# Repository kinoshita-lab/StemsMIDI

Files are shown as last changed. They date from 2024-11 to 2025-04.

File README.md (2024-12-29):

# STEMS MIDI: MIDI Controller for Traktor Stems (Dev board)

[日本語はこちら(Document in Japanese)](./README.ja.md)

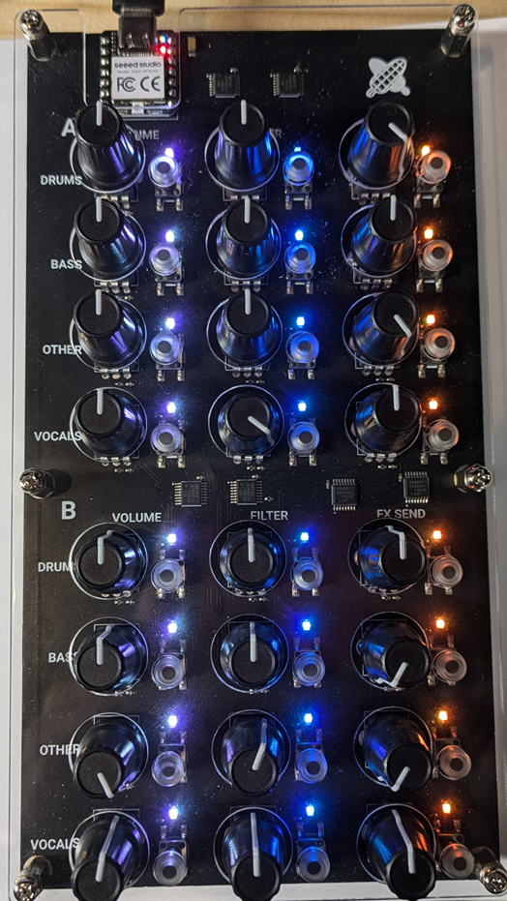
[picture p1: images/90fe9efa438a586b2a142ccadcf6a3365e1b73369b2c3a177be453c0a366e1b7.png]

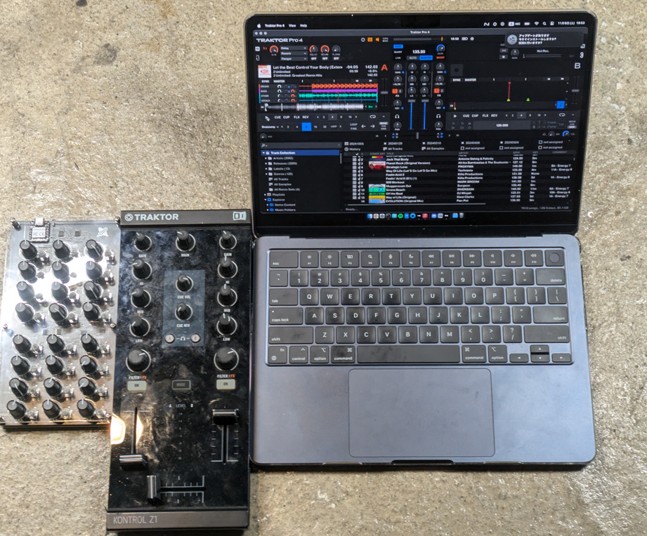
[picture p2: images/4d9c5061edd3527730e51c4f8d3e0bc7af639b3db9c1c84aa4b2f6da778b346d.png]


## ChangeLog
### Software
releases (https://github.com/kinoshita-lab/StemsMIDI/releases)

### Hardware Rev. 1.1
- [Hardware] Remove center-click feature for Vol and Effect knobs
- [Hardware] Add testing terminals on PCB

## Kit Contents

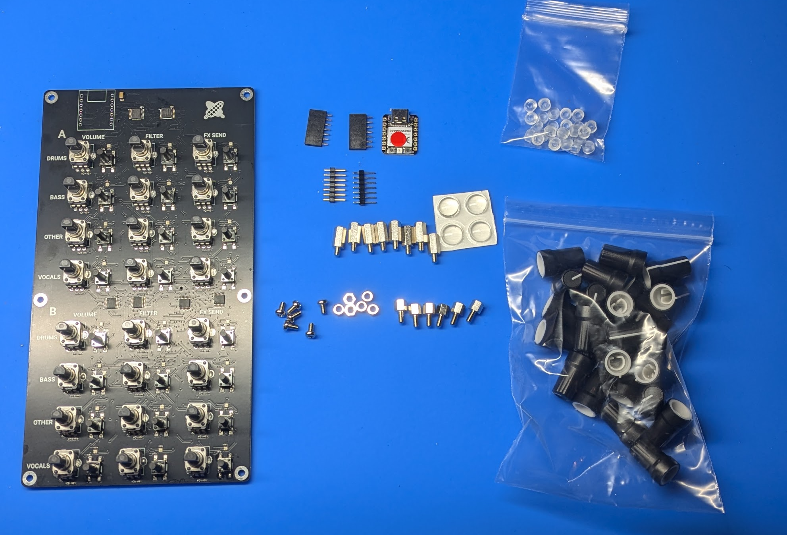
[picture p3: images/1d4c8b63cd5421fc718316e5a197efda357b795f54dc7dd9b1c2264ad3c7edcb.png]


- Pre-assembled PCB
- MCU Module Seeeduino XIAO RP2040(with flashed "sample" program)
- Pin Socket 1x7 (2 pcs.)
- Pin Header 1x7 (2 pcs.)
- Knob Caps (24 pcs.)
- Tactile switch Caps (24 pcs.)
- M3 Nuts (6 pcs.)
- M3 10mm Hex Spacers (6 pcs.)
- M3 7mm Hex Spacers (6 pcs.)
- M3 Screws (6 pcs.)
- Rubber feet pads(4 pcs.)
- Bottom Acrylic Panel (1 pcs.)
- Top Acrylic Panel (1 pcs.)

## Requied Equipments

- Solder Iron, Solder
- No.2 + Driver
- Plier and/or Wrench (for tightening nuts)

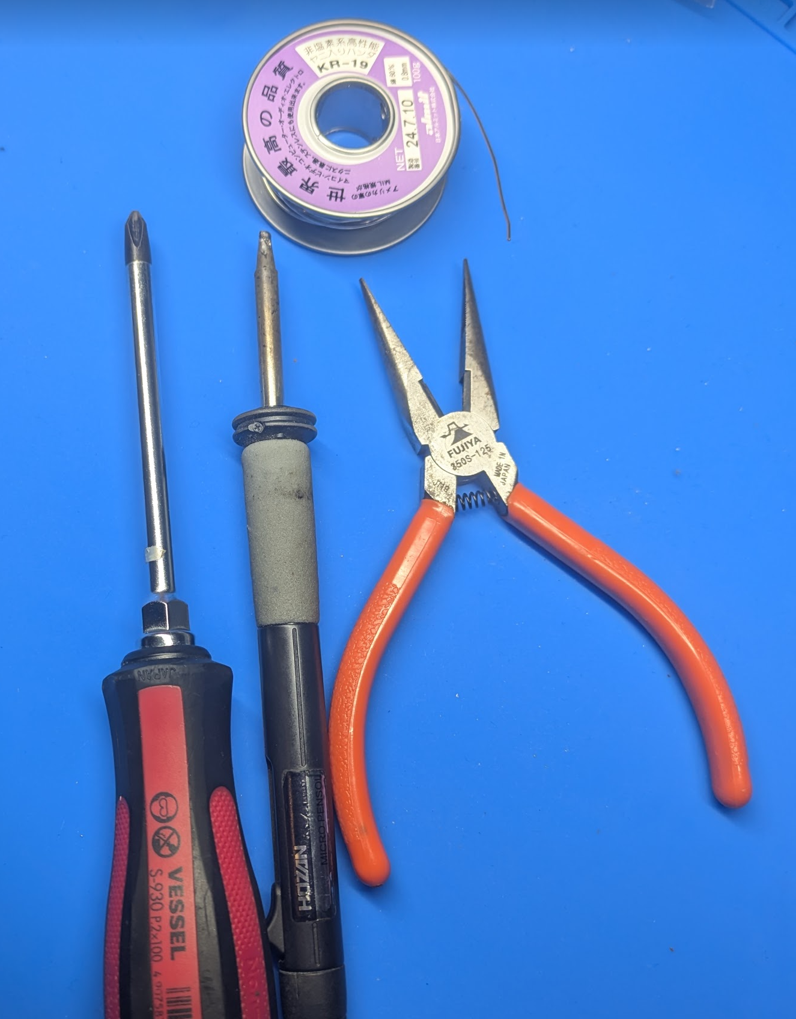
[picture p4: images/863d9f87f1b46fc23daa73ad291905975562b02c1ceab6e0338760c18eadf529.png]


## How to assemble

### Assemble the MCU Module

Recommend following procedure to align pins.
tips: You can solder MCU Module directly on the PCBA board.

Solder Pin Sockets, Pin Headers, and MCU. 1st, combine Pin Sockets and Headers as show below:

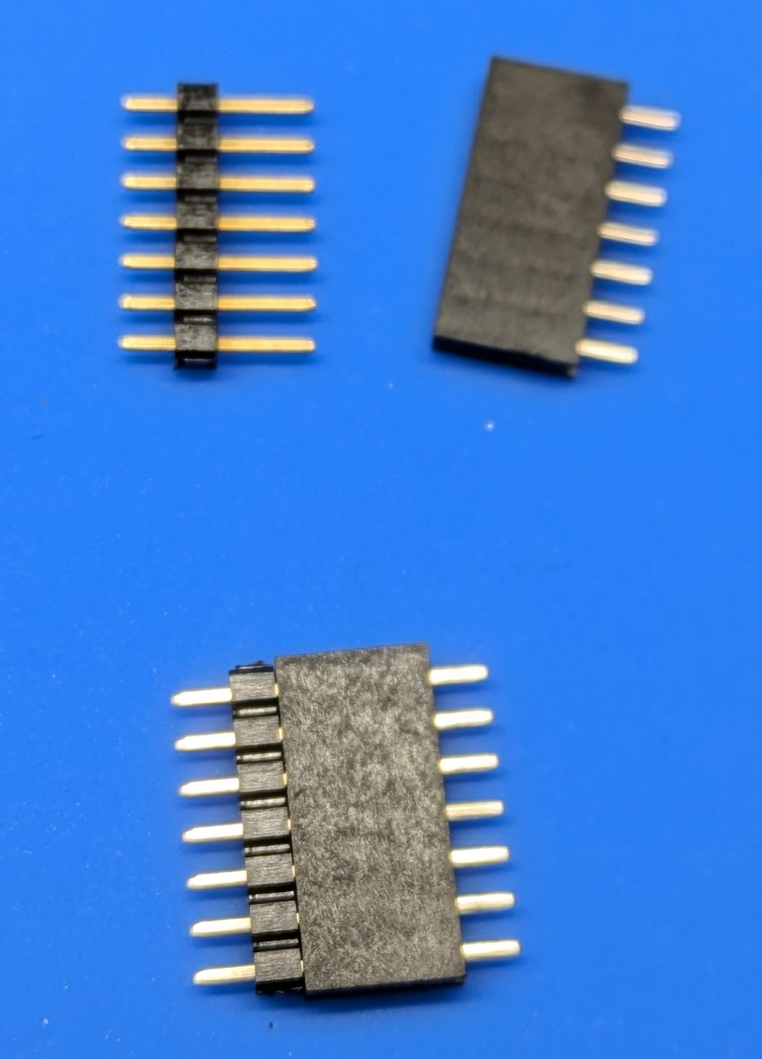
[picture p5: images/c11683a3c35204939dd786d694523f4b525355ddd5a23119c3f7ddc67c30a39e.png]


Put above result into MCU's both side holes as shown below:

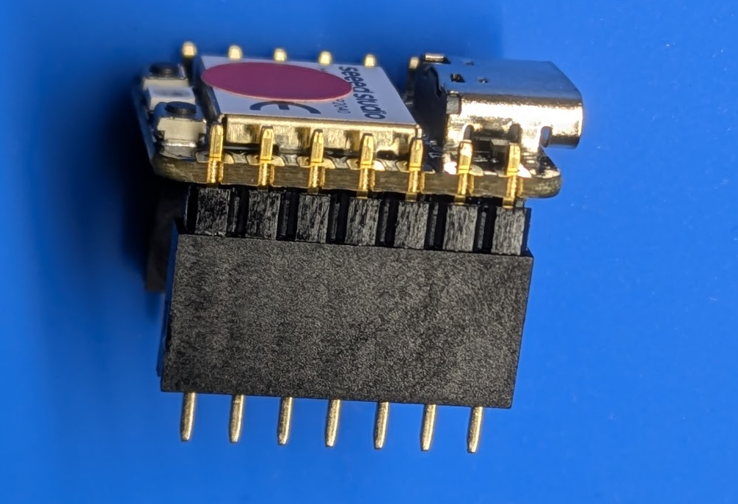
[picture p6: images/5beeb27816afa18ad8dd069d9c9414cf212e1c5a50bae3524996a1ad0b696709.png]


Put them on the holes of PCBA below:

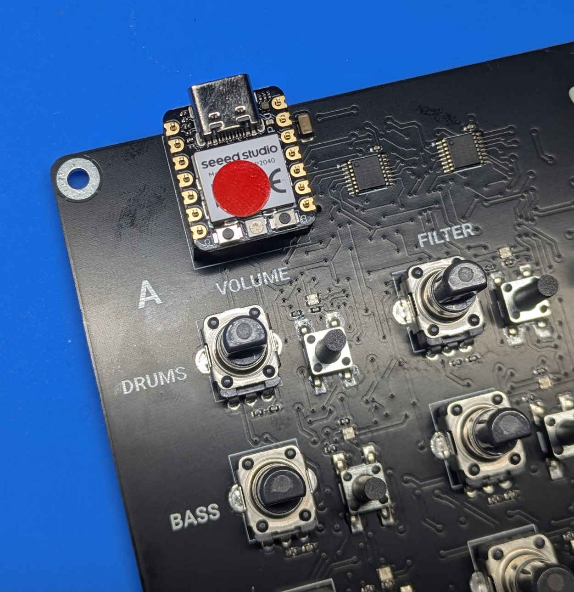
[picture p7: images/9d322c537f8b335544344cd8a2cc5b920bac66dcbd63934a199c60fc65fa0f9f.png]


Solder the Pin Header's MCU side:

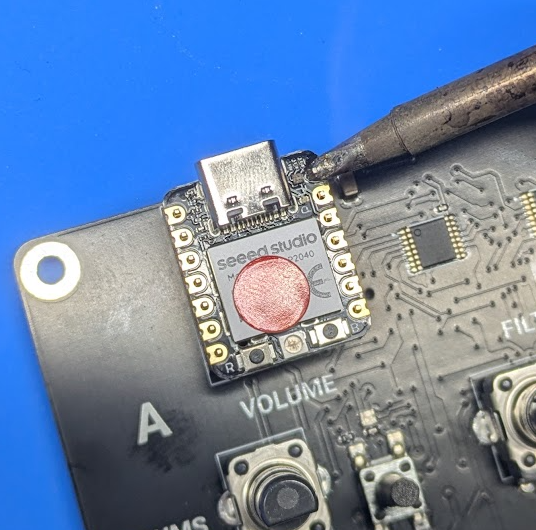
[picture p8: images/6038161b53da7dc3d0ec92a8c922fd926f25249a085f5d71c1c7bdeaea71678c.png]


Looks like below:

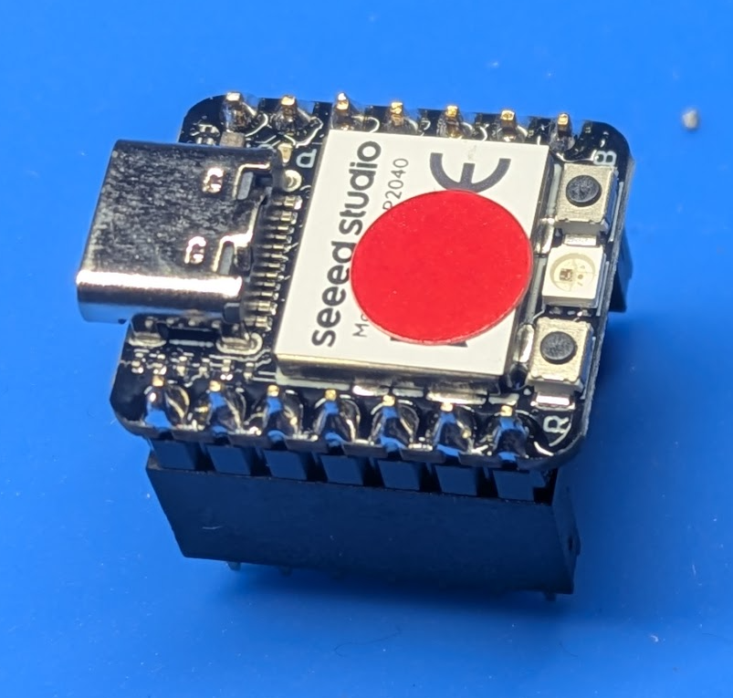
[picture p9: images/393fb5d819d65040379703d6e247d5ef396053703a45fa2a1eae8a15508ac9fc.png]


Put it again on the PCBA's holes:



Flip the PCBA board while holding the MCU module, with placing knob cap between MCU and the desk so that it can be held in place by its own weight.

Looks like below:

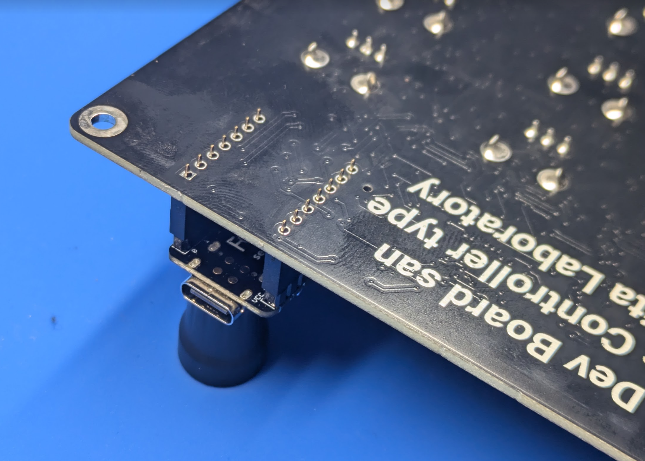
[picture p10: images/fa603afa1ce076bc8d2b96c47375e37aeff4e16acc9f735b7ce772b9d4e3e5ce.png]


Solder all the Pin socket's pin:

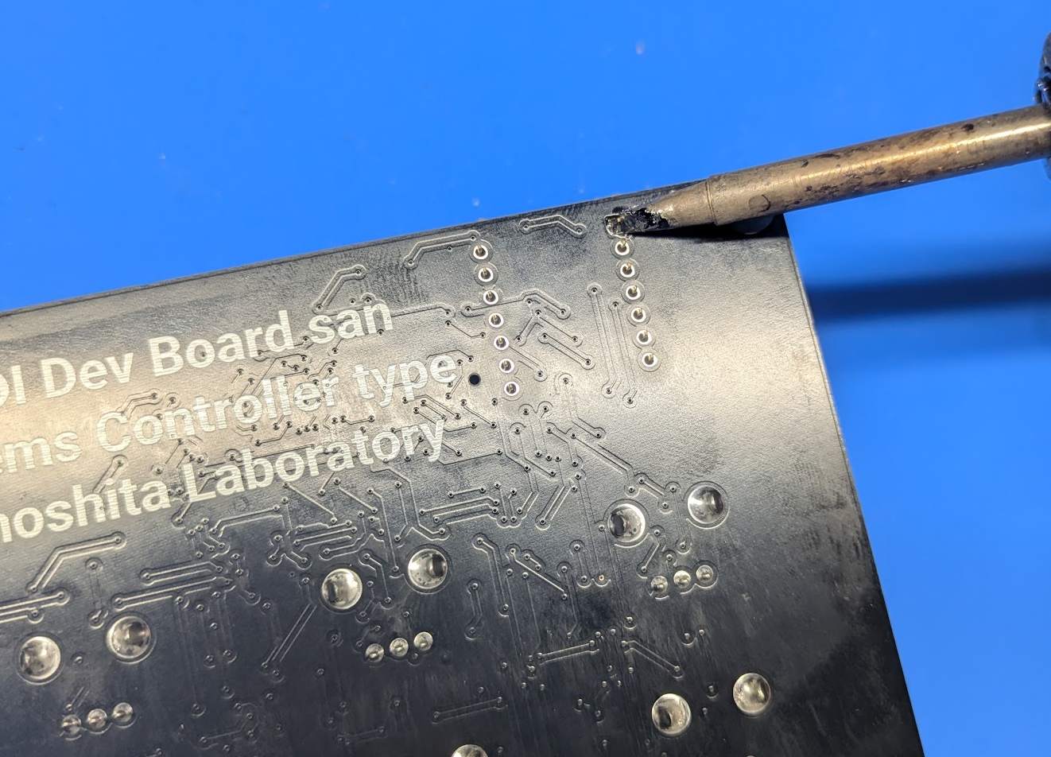
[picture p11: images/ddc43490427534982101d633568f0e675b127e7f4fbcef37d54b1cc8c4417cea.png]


### Assembling case

Peel off the protective sheet from the bottom acrylic panel, and attach nuts, M3  7mm Hex spacers hex screws (the shorter ones) at six locations.
(There are no two sides to the acrylic.):

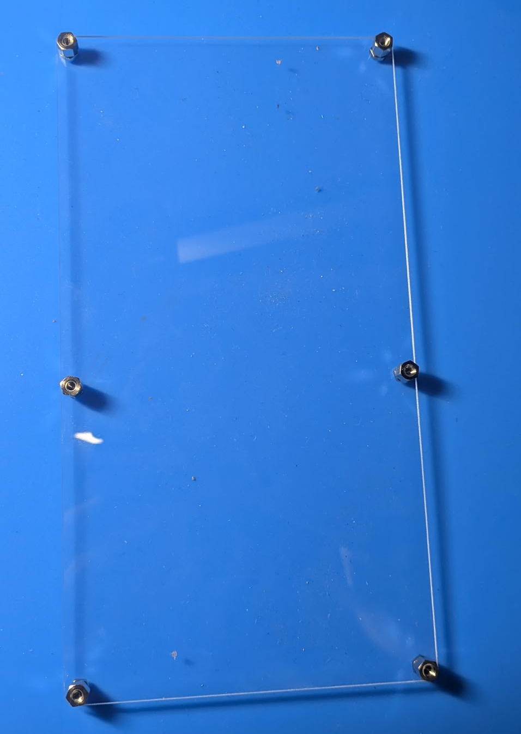
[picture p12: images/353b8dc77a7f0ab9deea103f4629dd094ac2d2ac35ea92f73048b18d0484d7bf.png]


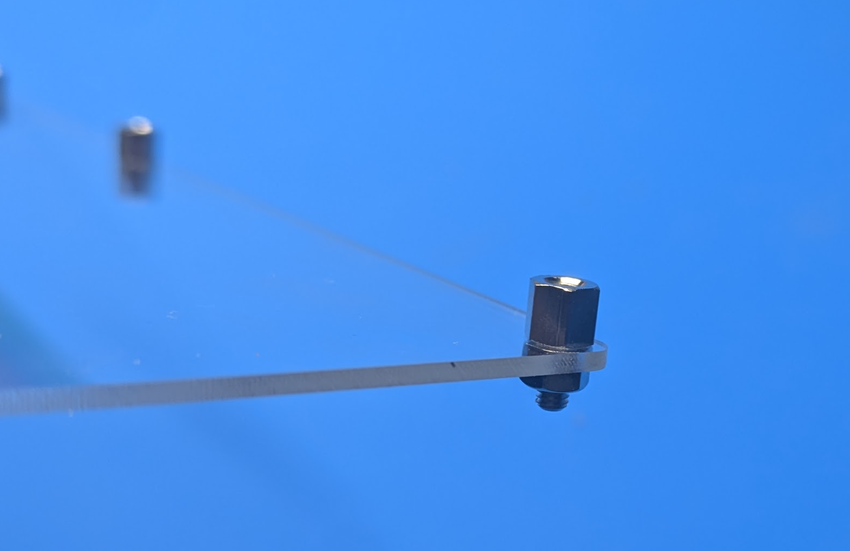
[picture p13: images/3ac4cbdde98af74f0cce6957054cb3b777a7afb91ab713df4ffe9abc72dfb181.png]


Put PCBA bord on it, tighten with the M3 10mm hex screws (the longer ones).
Tighten each screw little by little at to align the overall position:

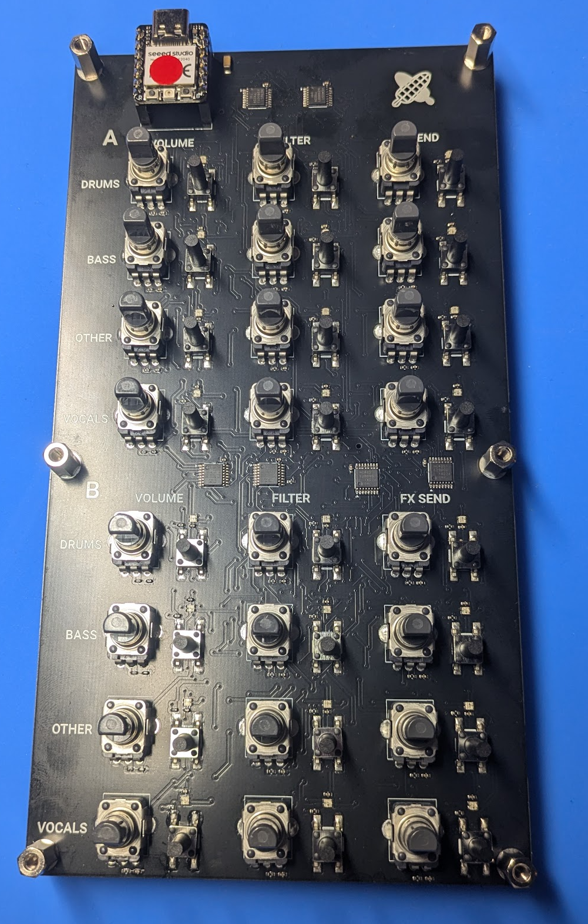
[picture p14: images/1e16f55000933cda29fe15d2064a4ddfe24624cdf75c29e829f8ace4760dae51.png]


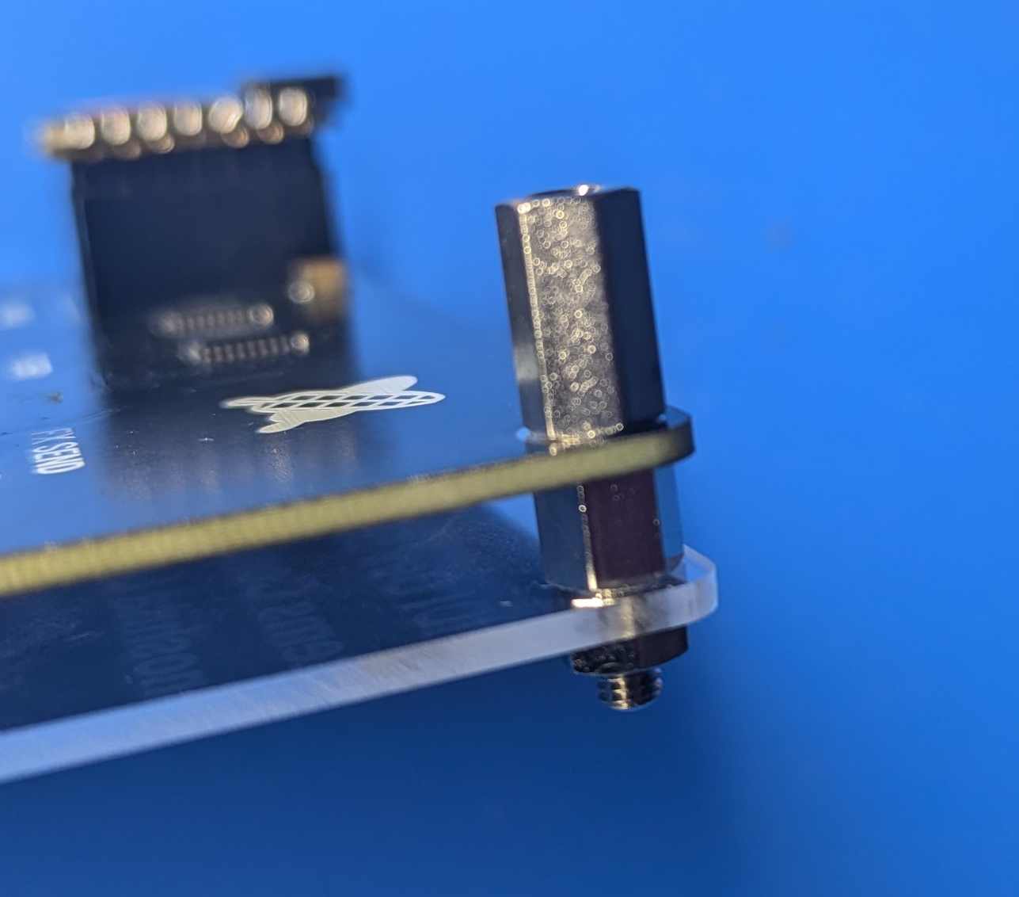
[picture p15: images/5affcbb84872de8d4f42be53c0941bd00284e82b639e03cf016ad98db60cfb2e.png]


Peel of the protective sheet from top acrylic panel and put it on the PCBA.
Tighten them with M3 screws.
Again, tighten each screw little by little at to align the overall position:

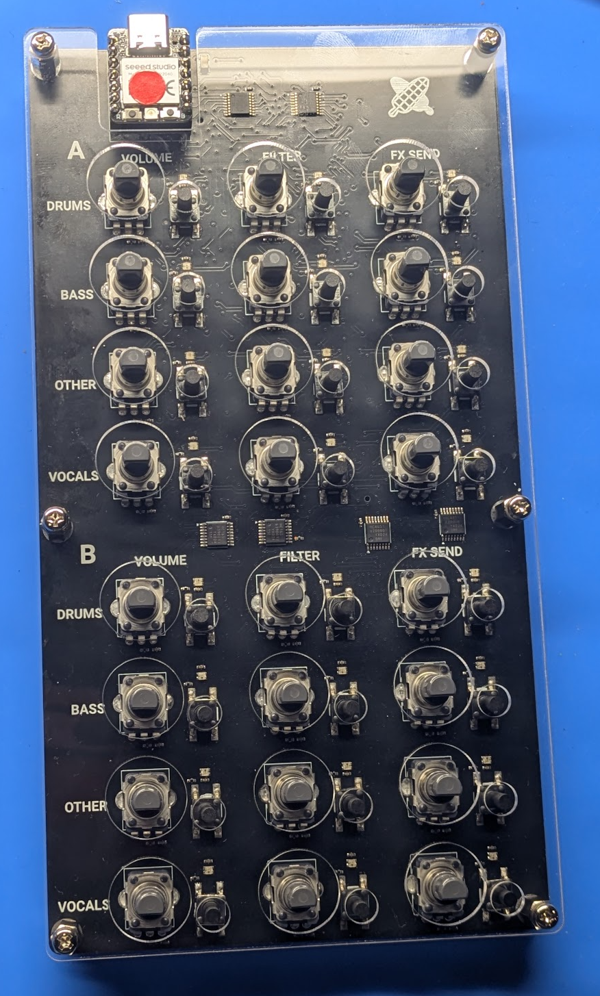
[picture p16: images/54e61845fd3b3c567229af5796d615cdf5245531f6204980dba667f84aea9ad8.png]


Put rubber feets on the bottom:

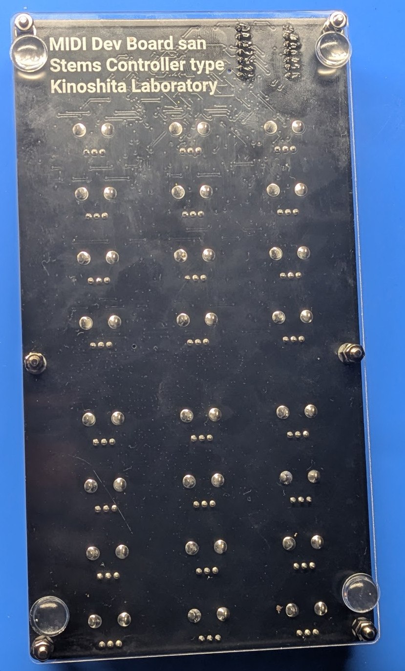
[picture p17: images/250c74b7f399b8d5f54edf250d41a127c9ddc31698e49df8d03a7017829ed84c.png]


Place knob caps:

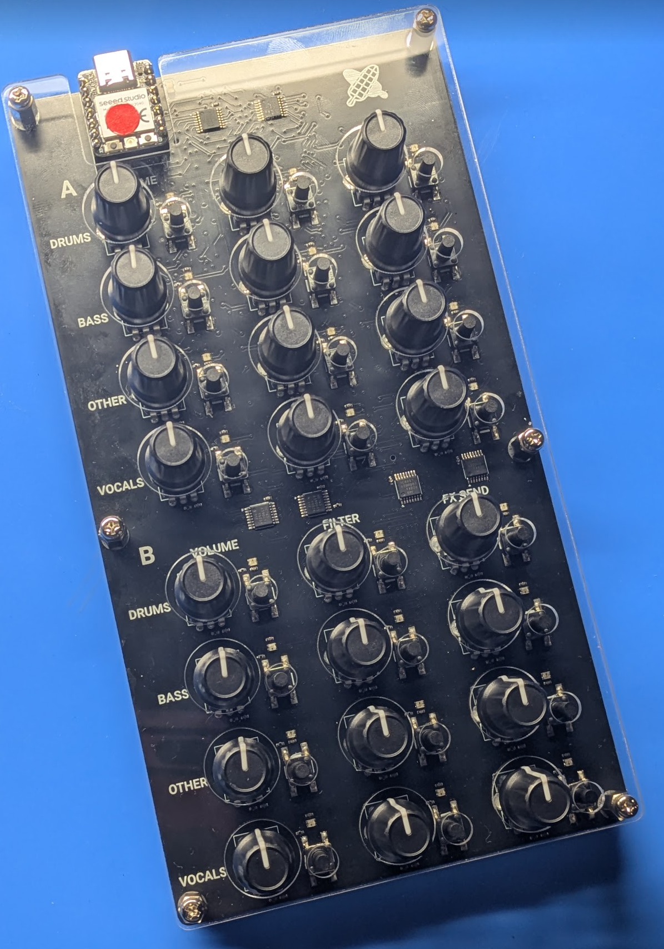
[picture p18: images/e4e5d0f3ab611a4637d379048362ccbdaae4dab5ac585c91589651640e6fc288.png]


Place tactile switch caps:

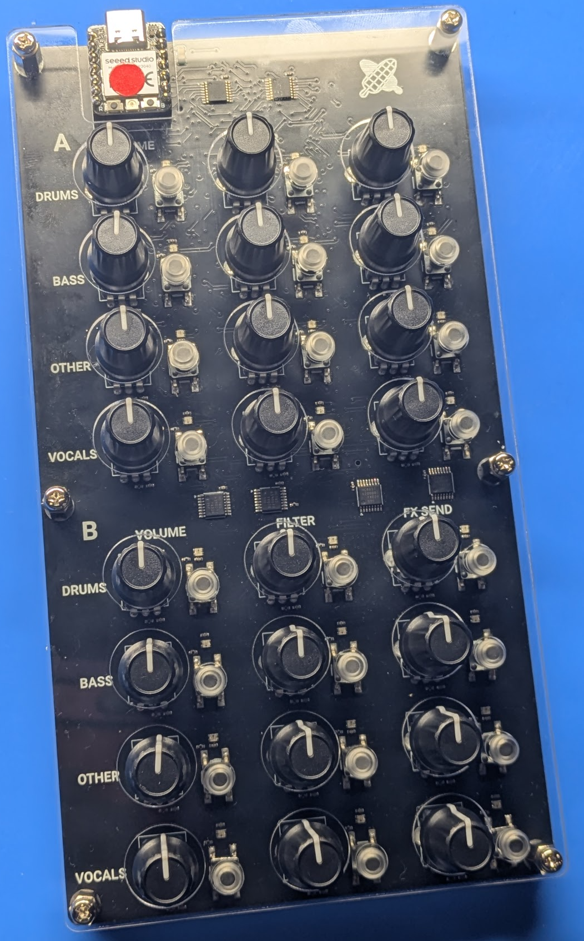
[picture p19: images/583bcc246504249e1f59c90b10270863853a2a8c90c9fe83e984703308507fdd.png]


## Usage

- Connect the product to PC/MAC.
- Import .tsi file below on Traktor.

<https://github.com/kinoshita-lab/StemsMIDI/tree/main/Traktor%20Setting>

## How to update Software

What you will need:

- Latest software to be flashed to the MCU(firmware.uf2) download from <https://github.com/kinoshita-lab/StemsMIDI/releases>
- PC or mac

Connect the USB cable with pressing the **B** button on the right bottom of the MCU.
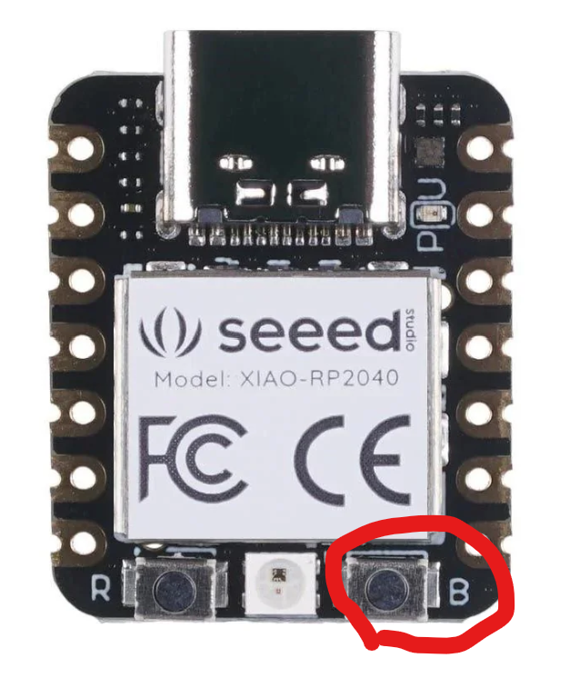
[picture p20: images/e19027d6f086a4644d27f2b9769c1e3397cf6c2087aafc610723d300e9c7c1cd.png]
  

After releasing the button, disk drive will appear on you PC/mac. The drive name is `RP-RP2`.

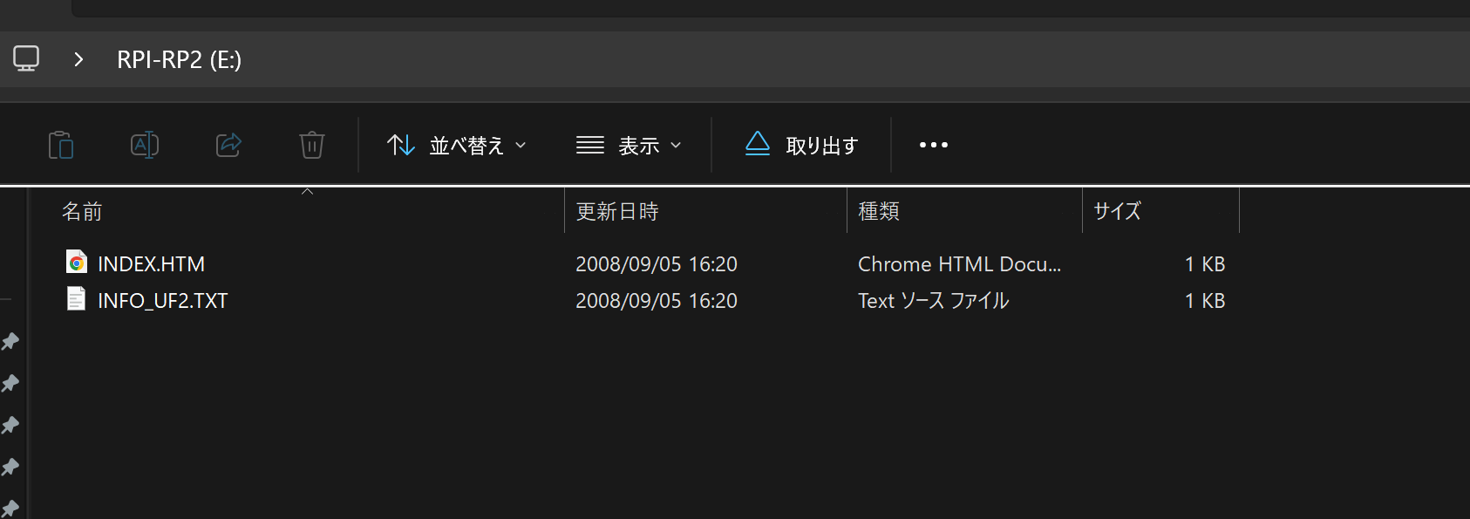
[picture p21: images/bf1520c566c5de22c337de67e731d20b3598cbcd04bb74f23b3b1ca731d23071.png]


Copy the firmware.uf2 file to the drive.
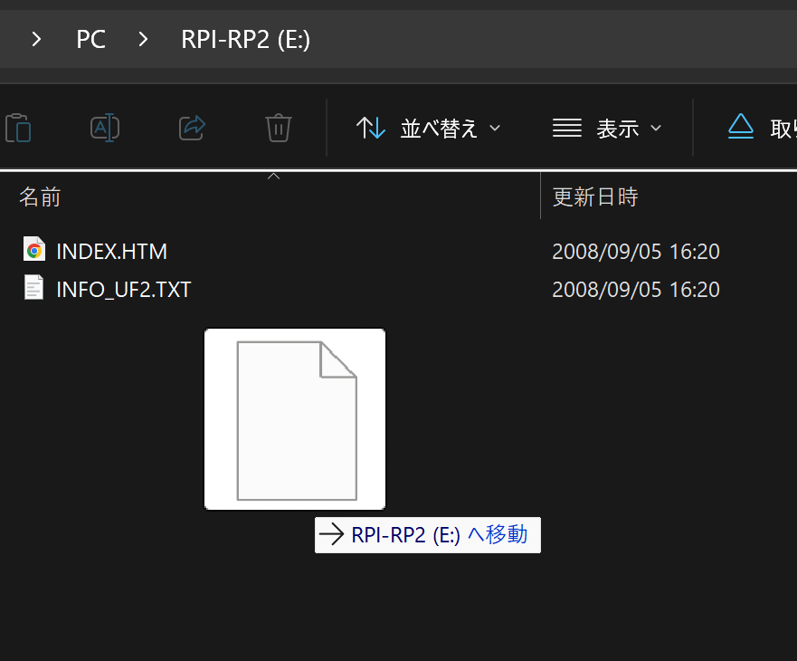
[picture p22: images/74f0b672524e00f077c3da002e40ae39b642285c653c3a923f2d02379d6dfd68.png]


Done updating, drive will automatically closed.

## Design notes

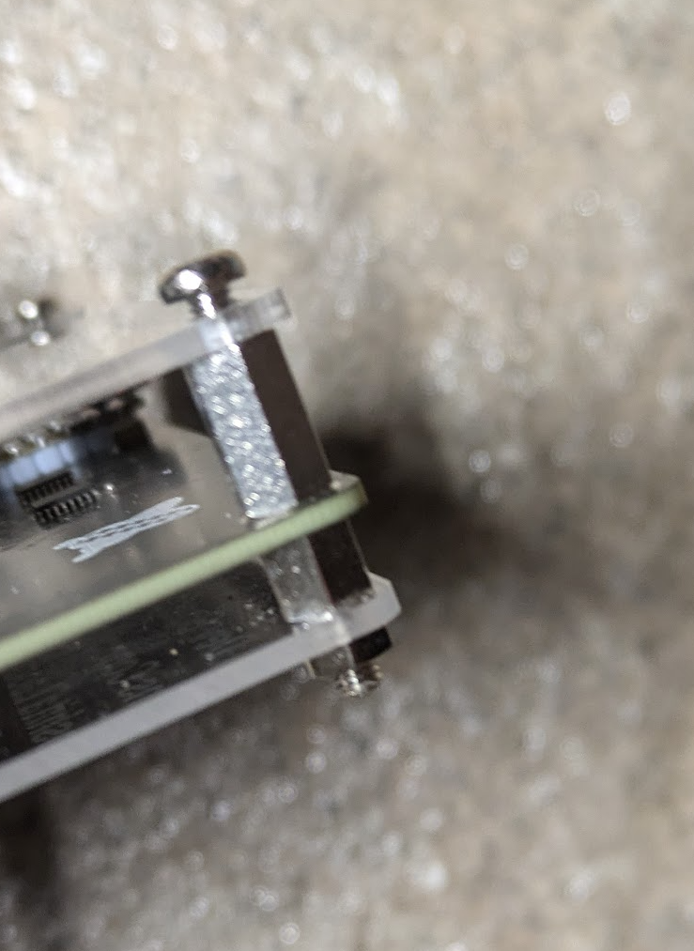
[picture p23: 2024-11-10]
images/7f1cb6cd50c7bb32835a7ec60418512192629a608fd293ecf4b8e06034ae1c80.png

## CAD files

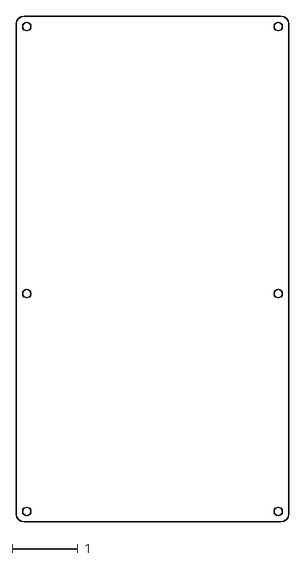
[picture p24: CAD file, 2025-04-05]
hard/Case/StemsMIDI_Case_Bottom-Edge_Cuts.dxf
4.13 x 7.68

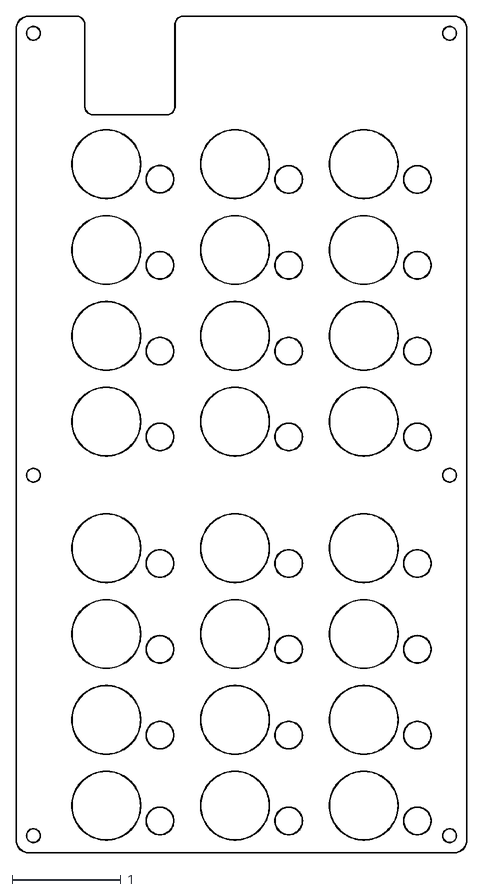
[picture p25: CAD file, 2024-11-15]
hard/Case/StemsMIDI_Case_Top_top-Edge_Cuts.dxf
4.14 x 7.68

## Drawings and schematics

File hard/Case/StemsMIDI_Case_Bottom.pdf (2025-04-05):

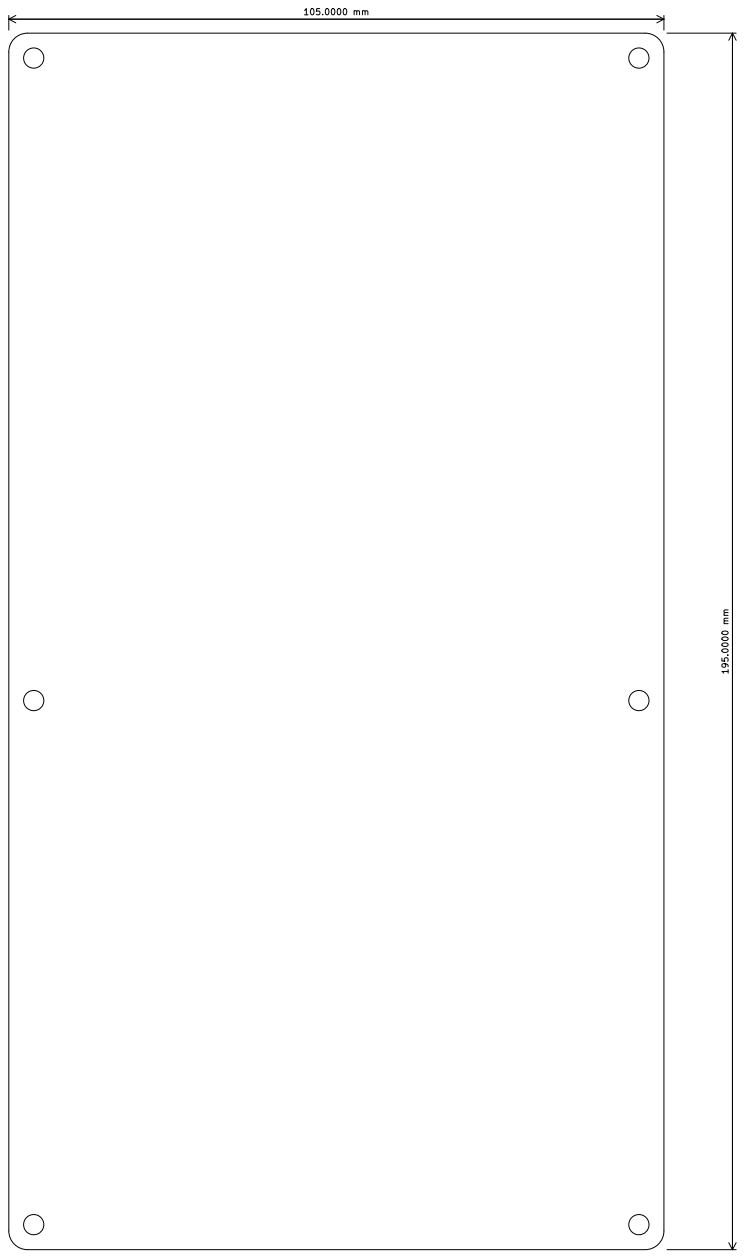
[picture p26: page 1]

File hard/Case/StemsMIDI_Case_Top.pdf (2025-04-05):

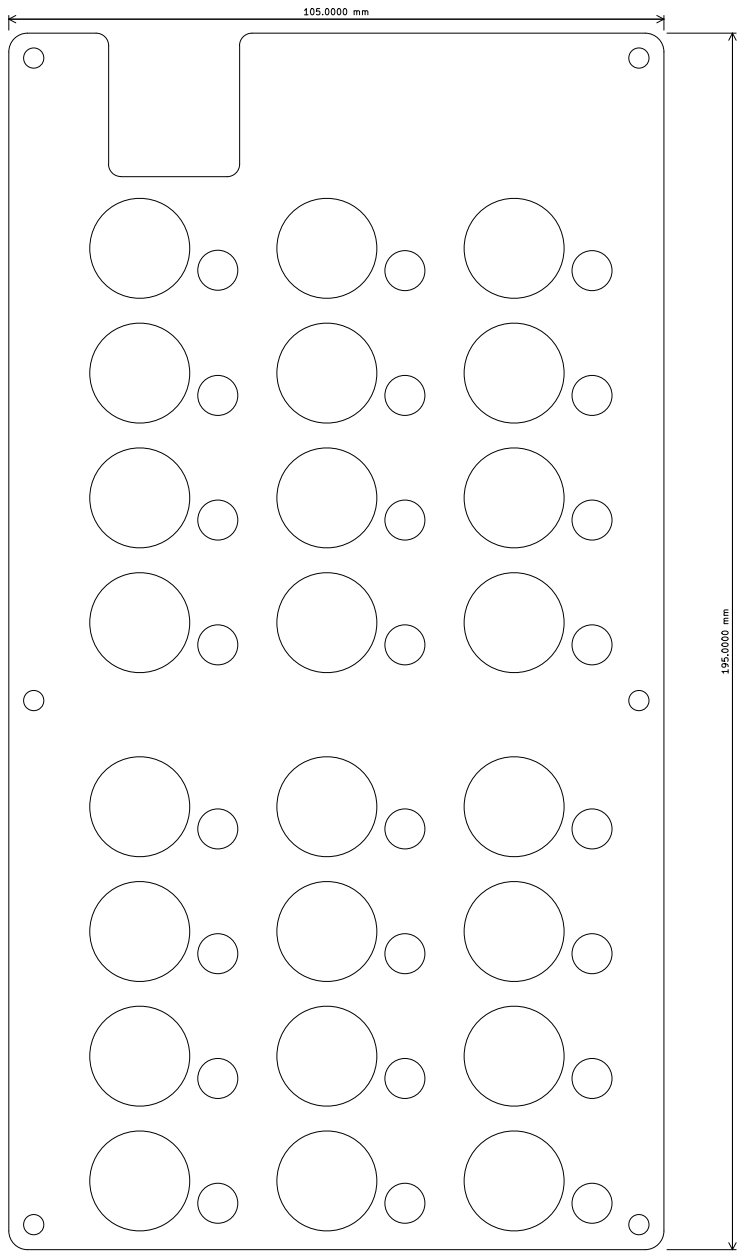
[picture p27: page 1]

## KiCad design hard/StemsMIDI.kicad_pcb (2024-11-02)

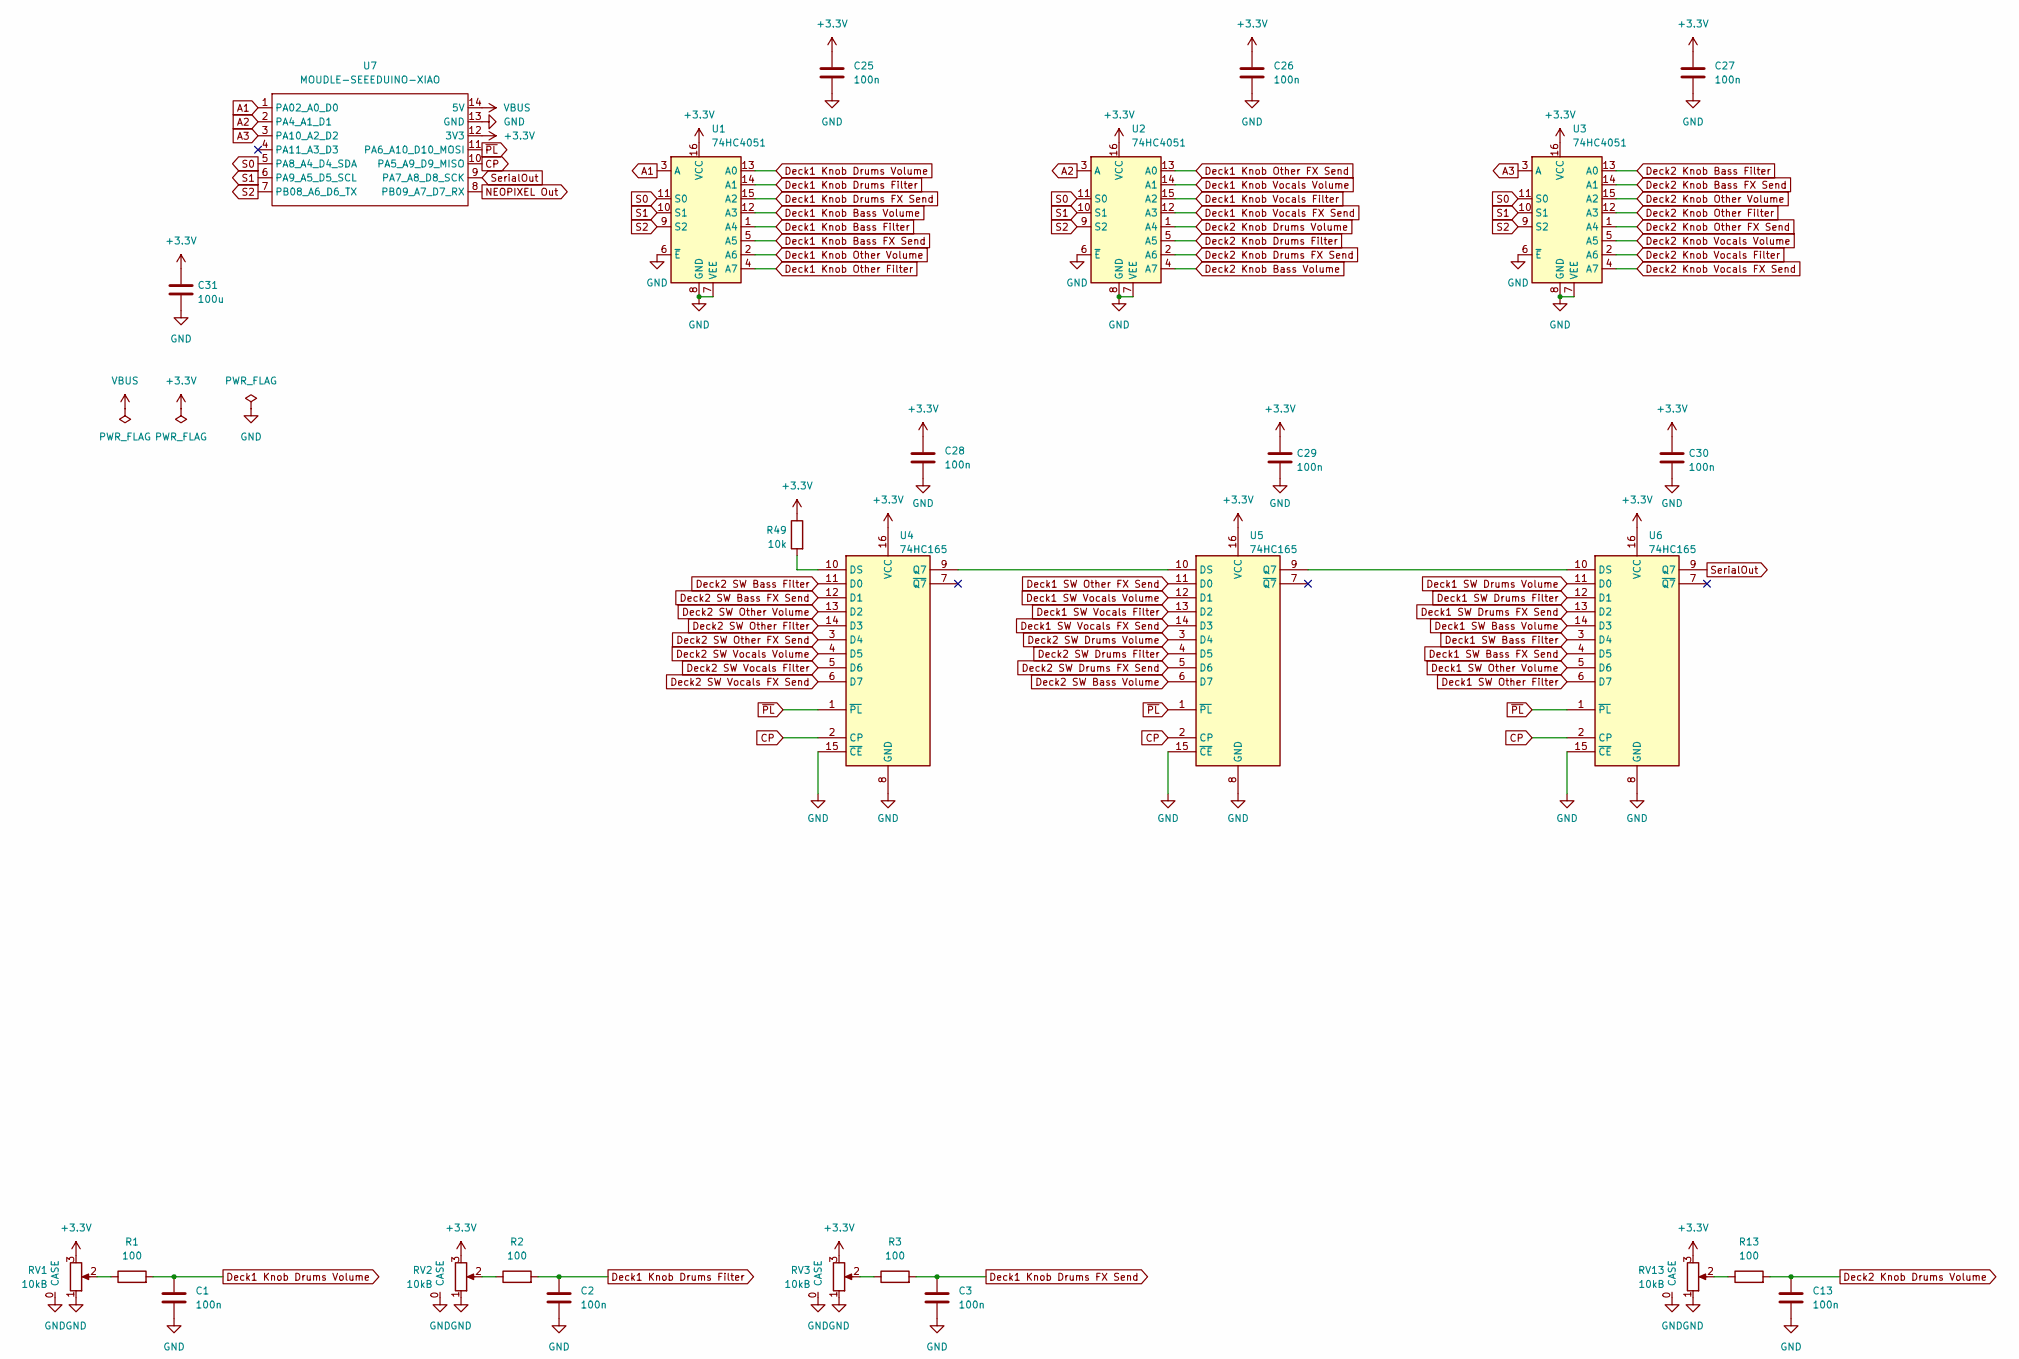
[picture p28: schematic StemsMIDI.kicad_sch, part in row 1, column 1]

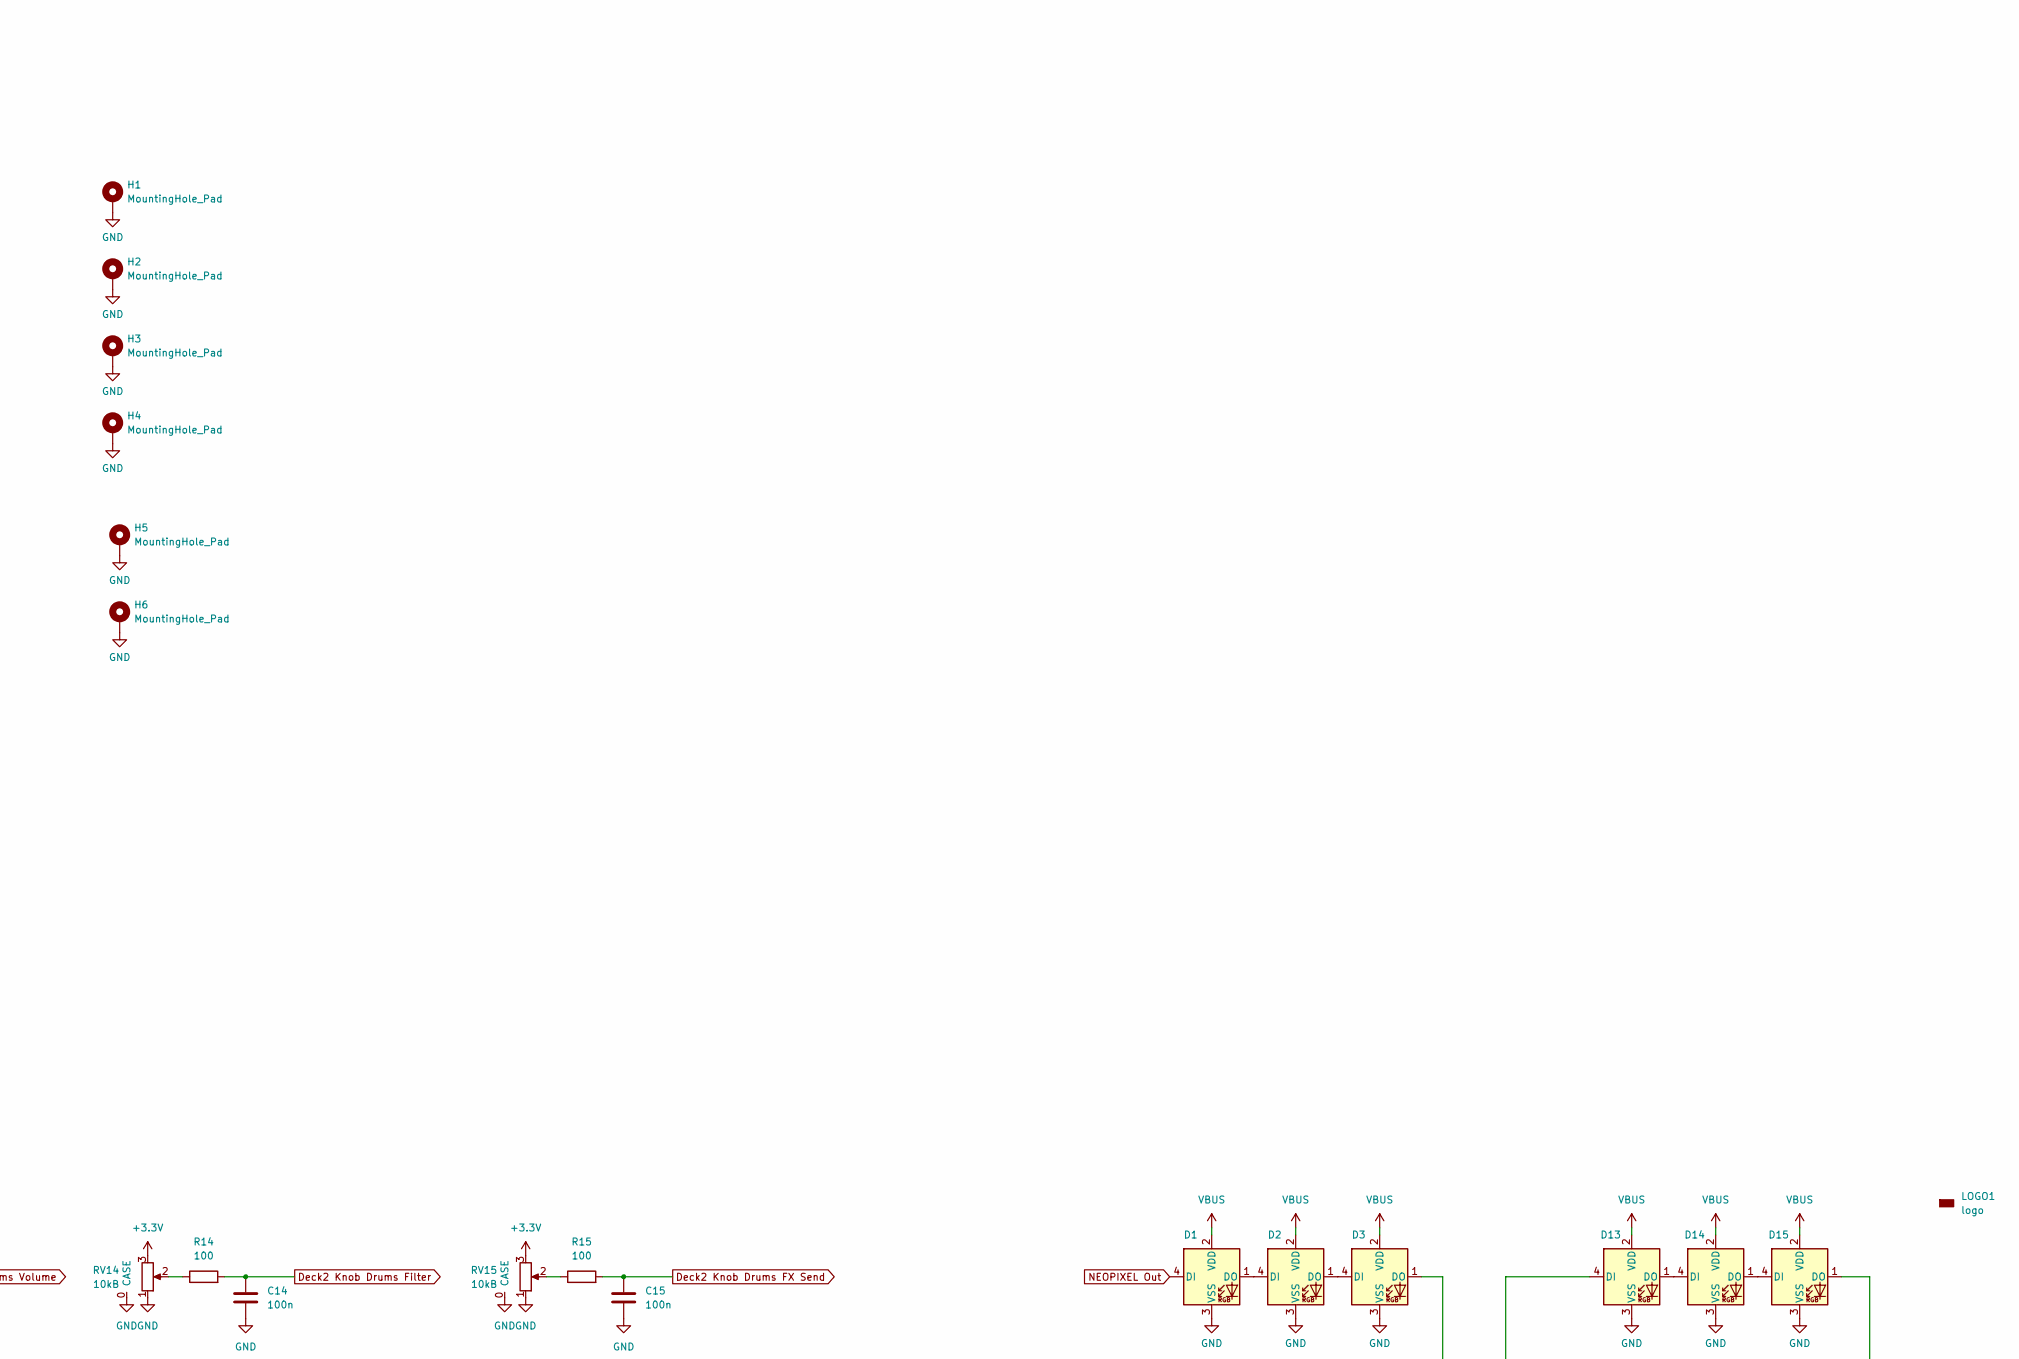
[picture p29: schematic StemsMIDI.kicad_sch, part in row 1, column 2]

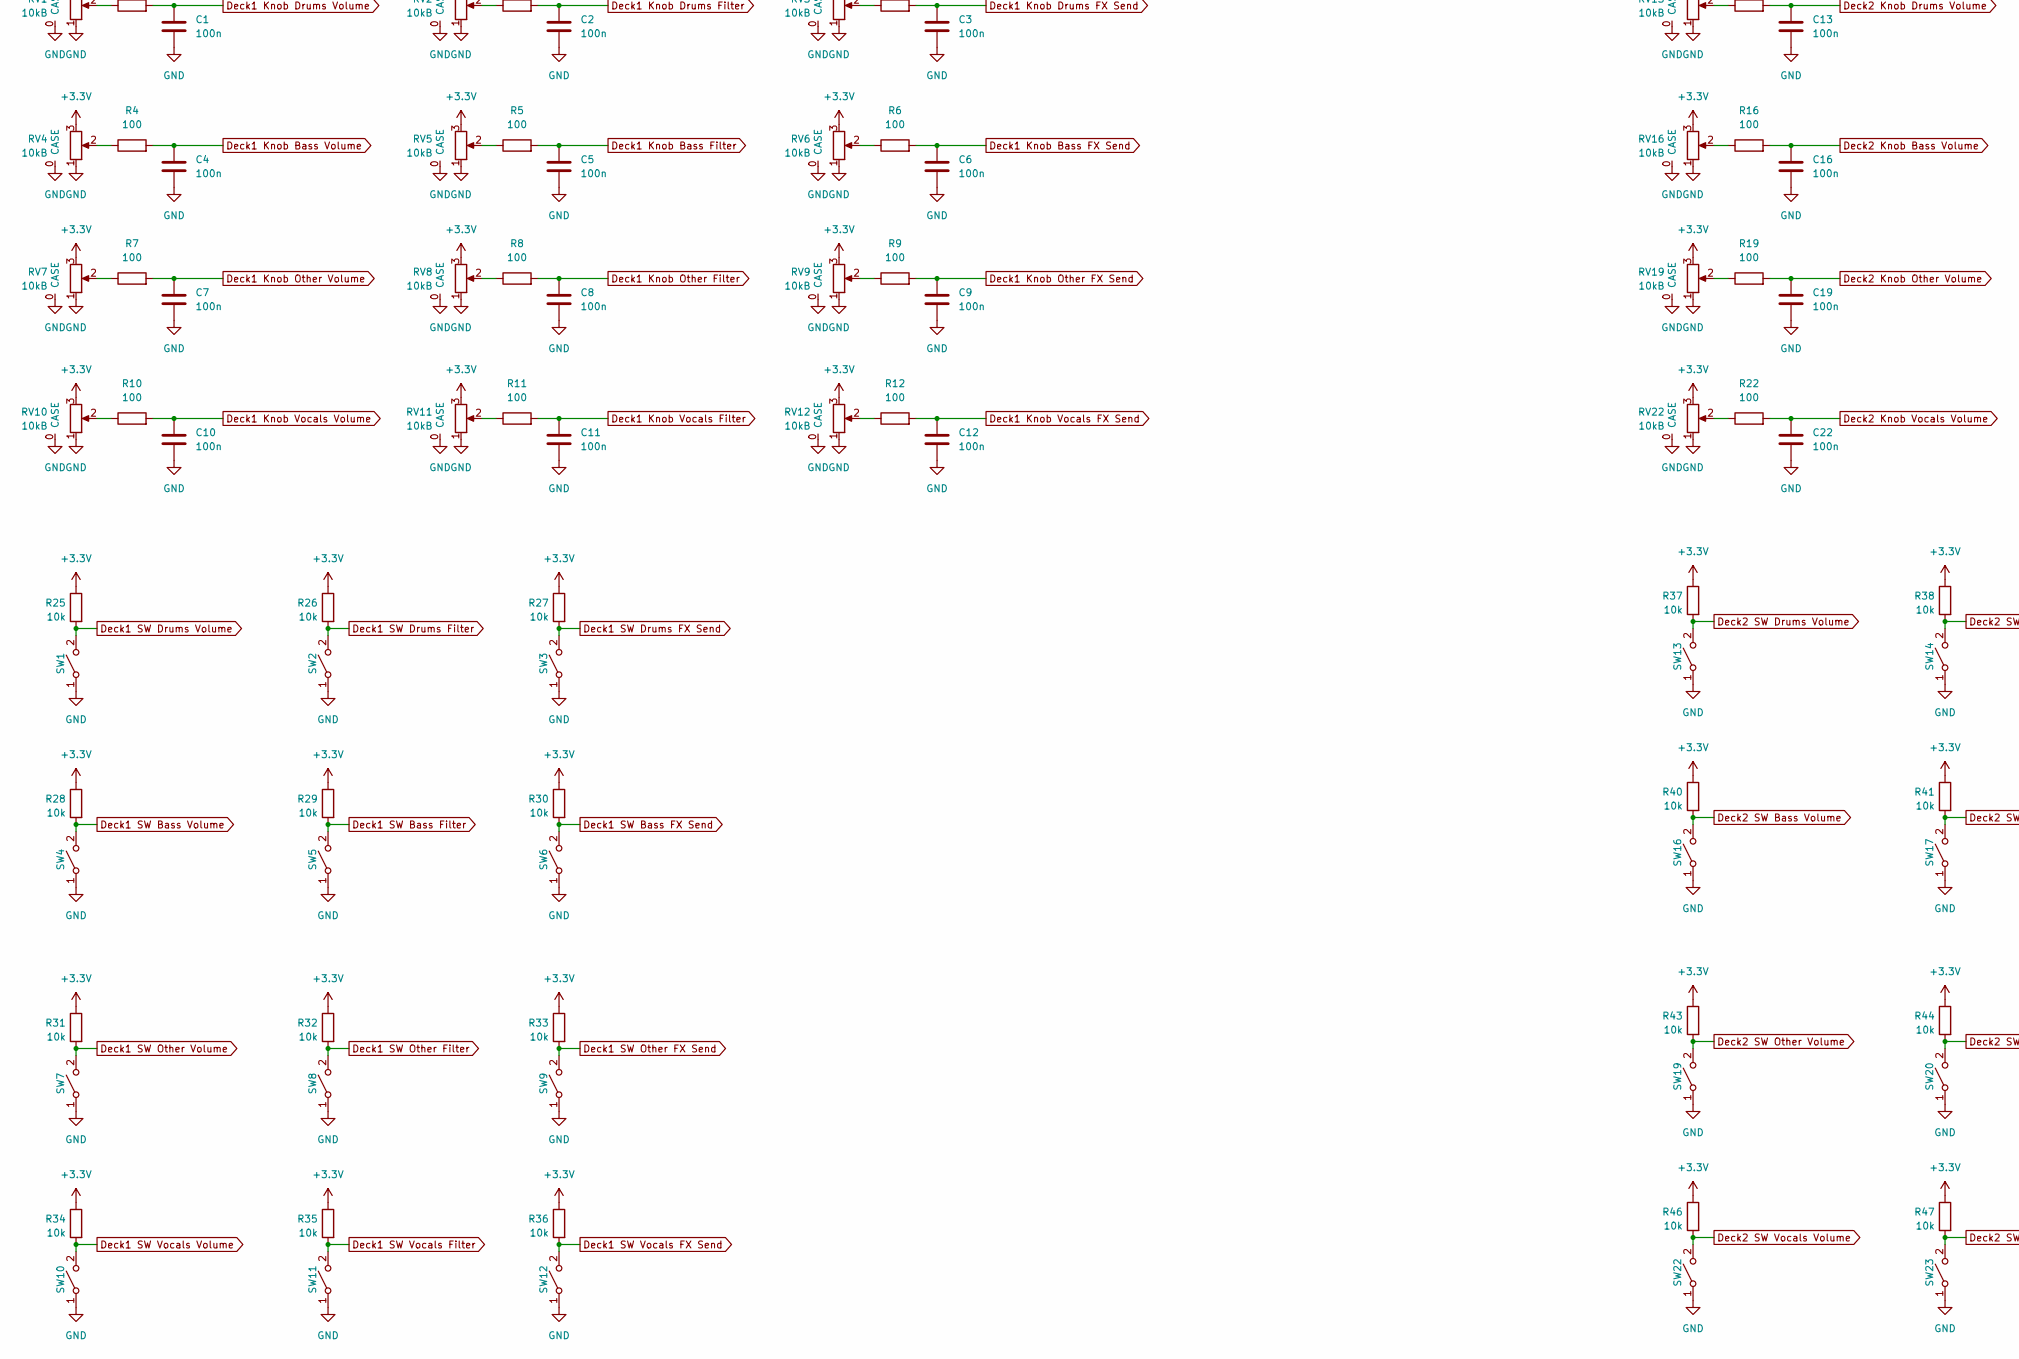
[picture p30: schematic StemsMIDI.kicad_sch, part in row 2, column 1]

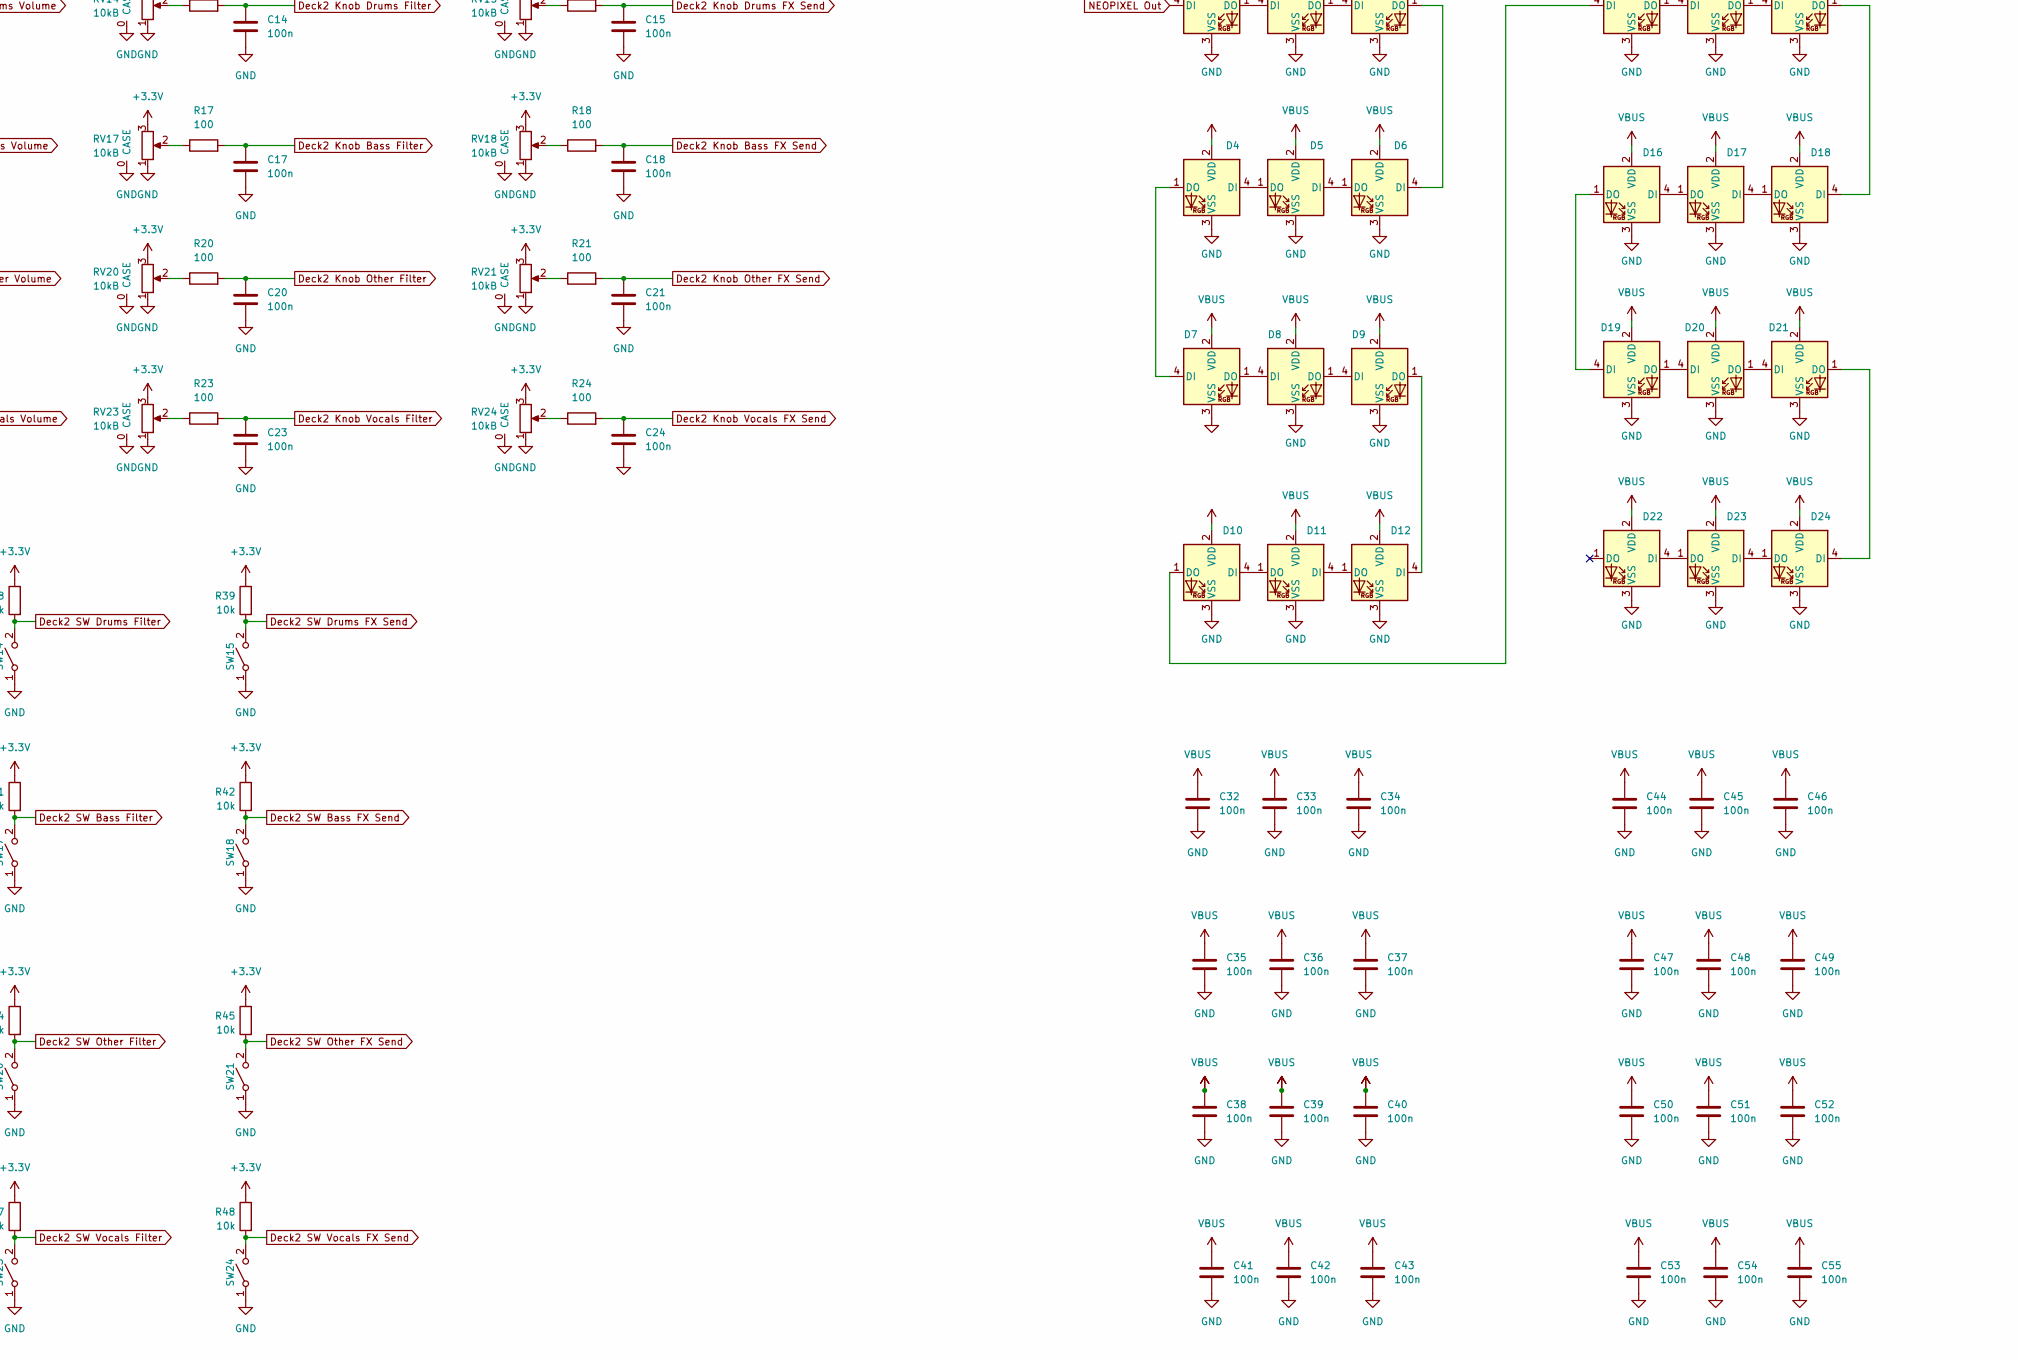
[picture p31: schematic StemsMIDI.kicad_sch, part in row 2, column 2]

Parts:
C1, C2, C3, C4, C5, C6, C7, C8, C9, C10, C11, C12, C13, C14, C15, C16, C17, C18, C19, C20, C21, C22, C23, C24, C25, C26, C27, C28, C29, C30, C32, C33, C34, C35, C36, C37, C38, C39, C40, C41, C42, C43, C44, C45, C46, C47, C48, C49, C50, C51, C52, C53, C54, C55: 100n; C_0402_1005Metric_Pad0.74x0.62mm_HandSolder; LCSC C1525
C31: 100u; C_1206_3216Metric_Pad1.33x1.80mm_HandSolder; LCSC C312983
D1, D2, D3, D4, D5, D6, D7, D8, D9, D10, D11, D12, D13, D14, D15, D16, D17, D18, D19, D20, D21, D22, D23, D24: LED_NeoPixel_XL-1615RGBC-WS2812B; LCSC C5349954
H1, H2, H3, H4, H5, H6: MountingHole_Pad; MountingHole_3.2mm_M3_Pad
LOGO1: logo; kinoshita-logo_simplified_300dpi
R1, R2, R3, R4, R5, R6, R7, R8, R9, R10, R11, R12, R13, R14, R15, R16, R17, R18, R19, R20, R21, R22, R23, R24: 100; R_0402_1005Metric_Pad0.72x0.64mm_HandSolder; LCSC C106232
R25, R26, R27, R28, R29, R30, R31, R32, R33, R34, R35, R36, R37, R38, R39, R40, R41, R42, R43, R44, R45, R46, R47, R48, R49: 10k; R_0402_1005Metric_Pad0.72x0.64mm_HandSolder; LCSC C25744
RV1, RV2, RV3, RV4, RV5, RV6, RV7, RV8, RV9, RV10, RV11, RV12, RV13, RV14, RV15, RV16, RV17, RV18, RV19, RV20, RV21, RV22, RV23, RV24: 10kB; Potentiometer_Alps_RK09K_Horizontal_CORRECTED; LCSC C470315
SW1, SW2, SW3, SW4, SW5, SW6, SW7, SW8, SW9, SW10, SW11, SW12, SW13, SW14, SW15, SW16, SW17, SW18, SW19, SW20, SW21, SW22, SW23, SW24: SW_SPST; SW_Tactile_6mm_x_6mm_Futsuuno_SMD; LCSC C2885193
U1, U2, U3: 74HC4051; TSSOP-16_4.4x5mm_P0.65mm; LCSC C5645
U4, U5, U6: 74HC165; TSSOP-16_4.4x5mm_P0.65mm; LCSC C80696
U7: MOUDLE-SEEEDUINO-XIAO; Seeduino_Xiao_RP2040_MOUDLE14P-2.54-21X17.8MM

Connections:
+3.3V: C25.1, C26.1, C27.1, C28.1, C29.1, C30.1, C31.1, R25.1, R26.1, R27.1, R28.1, R29.1, R30.1, R31.1, R32.1, R33.1, R34.1, R35.1, R36.1, R37.1, R38.1, R39.1, R40.1, R41.1, R42.1, R43.1, R44.1, R45.1, R46.1, R47.1, R48.1, R49.1, RV1.3, RV2.3, RV3.3, RV4.3, RV5.3, RV6.3, RV7.3, RV8.3, RV9.3, RV10.3, RV11.3, RV12.3, RV13.3, RV14.3, RV15.3, RV16.3, RV17.3, RV18.3, RV19.3, RV20.3, RV21.3, RV22.3, RV23.3, RV24.3, U1.16 (VCC), U2.16 (VCC), U3.16 (VCC), U4.16 (VCC), U5.16 (VCC), U6.16 (VCC), U7.12 (3V3)
A1: U1.3 (A), U7.1 (PA02_A0_D0)
A2: U2.3 (A), U7.2 (PA4_A1_D1)
A3: U3.3 (A), U7.3 (PA10_A2_D2)
CP: U4.2 (CP), U5.2 (CP), U6.2 (CP), U7.10 (PA5_A9_D9_MISO)
Deck1 Knob Bass FX Send: C6.1, R6.2, U1.5 (A5)
Deck1 Knob Bass Filter: C5.1, R5.2, U1.1 (A4)
Deck1 Knob Bass Volume: C4.1, R4.2, U1.12 (A3)
Deck1 Knob Drums FX Send: C3.1, R3.2, U1.15 (A2)
Deck1 Knob Drums Filter: C2.1, R2.2, U1.14 (A1)
Deck1 Knob Drums Volume: C1.1, R1.2, U1.13 (A0)
Deck1 Knob Other FX Send: C9.1, R9.2, U2.13 (A0)
Deck1 Knob Other Filter: C8.1, R8.2, U1.4 (A7)
Deck1 Knob Other Volume: C7.1, R7.2, U1.2 (A6)
Deck1 Knob Vocals FX Send: C12.1, R12.2, U2.12 (A3)
Deck1 Knob Vocals Filter: C11.1, R11.2, U2.15 (A2)
Deck1 Knob Vocals Volume: C10.1, R10.2, U2.14 (A1)
Deck1 SW Bass FX Send: R30.2, SW6.2 (B), U6.4 (D5)
Deck1 SW Bass Filter: R29.2, SW5.2 (B), U6.3 (D4)
Deck1 SW Bass Volume: R28.2, SW4.2 (B), U6.14 (D3)
Deck1 SW Drums FX Send: R27.2, SW3.2 (B), U6.13 (D2)
Deck1 SW Drums Filter: R26.2, SW2.2 (B), U6.12 (D1)
Deck1 SW Drums Volume: R25.2, SW1.2 (B), U6.11 (D0)
Deck1 SW Other FX Send: R33.2, SW9.2 (B), U5.11 (D0)
Deck1 SW Other Filter: R32.2, SW8.2 (B), U6.6 (D7)
Deck1 SW Other Volume: R31.2, SW7.2 (B), U6.5 (D6)
Deck1 SW Vocals FX Send: R36.2, SW12.2 (B), U5.14 (D3)
Deck1 SW Vocals Filter: R35.2, SW11.2 (B), U5.13 (D2)
Deck1 SW Vocals Volume: R34.2, SW10.2 (B), U5.12 (D1)
Deck2 Knob Bass FX Send: C18.1, R18.2, U3.14 (A1)
Deck2 Knob Bass Filter: C17.1, R17.2, U3.13 (A0)
Deck2 Knob Bass Volume: C16.1, R16.2, U2.4 (A7)
Deck2 Knob Drums FX Send: C15.1, R15.2, U2.2 (A6)
Deck2 Knob Drums Filter: C14.1, R14.2, U2.5 (A5)
Deck2 Knob Drums Volume: C13.1, R13.2, U2.1 (A4)
Deck2 Knob Other FX Send: C21.1, R21.2, U3.1 (A4)
Deck2 Knob Other Filter: C20.1, R20.2, U3.12 (A3)
Deck2 Knob Other Volume: C19.1, R19.2, U3.15 (A2)
Deck2 Knob Vocals FX Send: C24.1, R24.2, U3.4 (A7)
Deck2 Knob Vocals Filter: C23.1, R23.2, U3.2 (A6)
Deck2 Knob Vocals Volume: C22.1, R22.2, U3.5 (A5)
Deck2 SW Bass FX Send: R42.2, SW18.2 (B), U4.12 (D1)
Deck2 SW Bass Filter: R41.2, SW17.2 (B), U4.11 (D0)
Deck2 SW Bass Volume: R40.2, SW16.2 (B), U5.6 (D7)
Deck2 SW Drums FX Send: R39.2, SW15.2 (B), U5.5 (D6)
Deck2 SW Drums Filter: R38.2, SW14.2 (B), U5.4 (D5)
Deck2 SW Drums Volume: R37.2, SW13.2 (B), U5.3 (D4)
Deck2 SW Other FX Send: R45.2, SW21.2 (B), U4.3 (D4)
Deck2 SW Other Filter: R44.2, SW20.2 (B), U4.14 (D3)
Deck2 SW Other Volume: R43.2, SW19.2 (B), U4.13 (D2)
Deck2 SW Vocals FX Send: R48.2, SW24.2 (B), U4.6 (D7)
Deck2 SW Vocals Filter: R47.2, SW23.2 (B), U4.5 (D6)
Deck2 SW Vocals Volume: R46.2, SW22.2 (B), U4.4 (D5)
GND: C1.2, C2.2, C3.2, C4.2, C5.2, C6.2, C7.2, C8.2, C9.2, C10.2, C11.2, C12.2, C13.2, C14.2, C15.2, C16.2, C17.2, C18.2, C19.2, C20.2, C21.2, C22.2, C23.2, C24.2, C25.2, C26.2, C27.2, C28.2, C29.2, C30.2, C31.2, C32.2, C33.2, C34.2, C35.2, C36.2, C37.2, C38.2, C39.2, C40.2, C41.2, C42.2, C43.2, C44.2, C45.2, C46.2, C47.2, C48.2, C49.2, C50.2, C51.2, C52.2, C53.2, C54.2, C55.2, D1.3 (VSS), D2.3 (VSS), D3.3 (VSS), D4.3 (VSS), D5.3 (VSS), D6.3 (VSS), D7.3 (VSS), D8.3 (VSS), D9.3 (VSS), D10.3 (VSS), D11.3 (VSS), D12.3 (VSS), D13.3 (VSS), D14.3 (VSS), D15.3 (VSS), D16.3 (VSS), D17.3 (VSS), D18.3 (VSS), D19.3 (VSS), D20.3 (VSS), D21.3 (VSS), D22.3 (VSS), D23.3 (VSS), D24.3 (VSS), H1.1, H2.1, H3.1, H4.1, H5.1, H6.1, RV1.0 (CASE), RV1.1, RV2.0 (CASE), RV2.1, RV3.0 (CASE), RV3.1, RV4.0 (CASE), RV4.1, RV5.0 (CASE), RV5.1, RV6.0 (CASE), RV6.1, RV7.0 (CASE), RV7.1, RV8.0 (CASE), RV8.1, RV9.0 (CASE), RV9.1, RV10.0 (CASE), RV10.1, RV11.0 (CASE), RV11.1, RV12.0 (CASE), RV12.1, RV13.0 (CASE), RV13.1, RV14.0 (CASE), RV14.1, RV15.0 (CASE), RV15.1, RV16.0 (CASE), RV16.1, RV17.0 (CASE), RV17.1, RV18.0 (CASE), RV18.1, RV19.0 (CASE), RV19.1, RV20.0 (CASE), RV20.1, RV21.0 (CASE), RV21.1, RV22.0 (CASE), RV22.1, RV23.0 (CASE), RV23.1, RV24.0 (CASE), RV24.1, SW1.1 (A), SW2.1 (A), SW3.1 (A), SW4.1 (A), SW5.1 (A), SW6.1 (A), SW7.1 (A), SW8.1 (A), SW9.1 (A), SW10.1 (A), SW11.1 (A), SW12.1 (A), SW13.1 (A), SW14.1 (A), SW15.1 (A), SW16.1 (A), SW17.1 (A), SW18.1 (A), SW19.1 (A), SW20.1 (A), SW21.1 (A), SW22.1 (A), SW23.1 (A), SW24.1 (A), U1.6 (~E), U1.7 (VEE), U1.8 (GND), U2.6 (~E), U2.7 (VEE), U2.8 (GND), U3.6 (~E), U3.7 (VEE), U3.8 (GND), U4.8 (GND), U4.15 (~CE), U5.8 (GND), U5.15 (~CE), U6.8 (GND), U6.15 (~CE), U7.13 (GND)
NEOPIXEL Out: D1.4 (DI), U7.8 (PB09_A7_D7_RX)
unnamed: D1.1 (DO), D2.4 (DI)
unnamed: D2.1 (DO), D3.4 (DI)
unnamed: D3.1 (DO), D6.4 (DI)
unnamed: D4.4 (DI), D5.1 (DO)
unnamed: D4.1 (DO), D7.4 (DI)
unnamed: D5.4 (DI), D6.1 (DO)
unnamed: D7.1 (DO), D8.4 (DI)
unnamed: D8.1 (DO), D9.4 (DI)
unnamed: D10.4 (DI), D11.1 (DO)
unnamed: D10.1 (DO), D13.4 (DI)
unnamed: D11.4 (DI), D12.1 (DO)
unnamed: D9.1 (DO), D12.4 (DI)
unnamed: D13.1 (DO), D14.4 (DI)
unnamed: D14.1 (DO), D15.4 (DI)
unnamed: D15.1 (DO), D18.4 (DI)
unnamed: D16.4 (DI), D17.1 (DO)
unnamed: D16.1 (DO), D19.4 (DI)
unnamed: D17.4 (DI), D18.1 (DO)
unnamed: D19.1 (DO), D20.4 (DI)
unnamed: D20.1 (DO), D21.4 (DI)
unnamed: D21.1 (DO), D24.4 (DI)
unnamed: D22.4 (DI), D23.1 (DO)
unnamed: D23.4 (DI), D24.1 (DO)
unnamed: R1.1, RV1.2
unnamed: R2.1, RV2.2
unnamed: R3.1, RV3.2
unnamed: R4.1, RV4.2
unnamed: R5.1, RV5.2
unnamed: R6.1, RV6.2
unnamed: R7.1, RV7.2
unnamed: R8.1, RV8.2
unnamed: R9.1, RV9.2
unnamed: R10.1, RV10.2
unnamed: R11.1, RV11.2
unnamed: R12.1, RV12.2
unnamed: R13.1, RV13.2
unnamed: R14.1, RV14.2
unnamed: R15.1, RV15.2
unnamed: R16.1, RV16.2
unnamed: R17.1, RV17.2
unnamed: R18.1, RV18.2
unnamed: R19.1, RV19.2
unnamed: R20.1, RV20.2
unnamed: R21.1, RV21.2
unnamed: R22.1, RV22.2
unnamed: R23.1, RV23.2
unnamed: R24.1, RV24.2
unnamed: R49.2, U4.10 (DS)
unnamed: U4.9 (Q7), U5.10 (DS)
unnamed: U5.9 (Q7), U6.10 (DS)
S0: U1.11 (S0), U2.11 (S0), U3.11 (S0), U7.5 (PA8_A4_D4_SDA)
S1: U1.10 (S1), U2.10 (S1), U3.10 (S1), U7.6 (PA9_A5_D5_SCL)
S2: U1.9 (S2), U2.9 (S2), U3.9 (S2), U7.7 (PB08_A6_D6_TX)
SerialOut: U6.9 (Q7), U7.9 (PA7_A8_D8_SCK)
VBUS: C32.1, C33.1, C34.1, C35.1, C36.1, C37.1, C38.1, C39.1, C40.1, C41.1, C42.1, C43.1, C44.1, C45.1, C46.1, C47.1, C48.1, C49.1, C50.1, C51.1, C52.1, C53.1, C54.1, C55.1, D1.2 (VDD), D2.2 (VDD), D3.2 (VDD), D4.2 (VDD), D5.2 (VDD), D6.2 (VDD), D7.2 (VDD), D8.2 (VDD), D9.2 (VDD), D10.2 (VDD), D11.2 (VDD), D12.2 (VDD), D13.2 (VDD), D14.2 (VDD), D15.2 (VDD), D16.2 (VDD), D17.2 (VDD), D18.2 (VDD), D19.2 (VDD), D20.2 (VDD), D21.2 (VDD), D22.2 (VDD), D23.2 (VDD), D24.2 (VDD), U7.14 (5V)
~PL: U4.1 (~PL), U5.1 (~PL), U6.1 (~PL), U7.11 (PA6_A10_D10_MOSI)

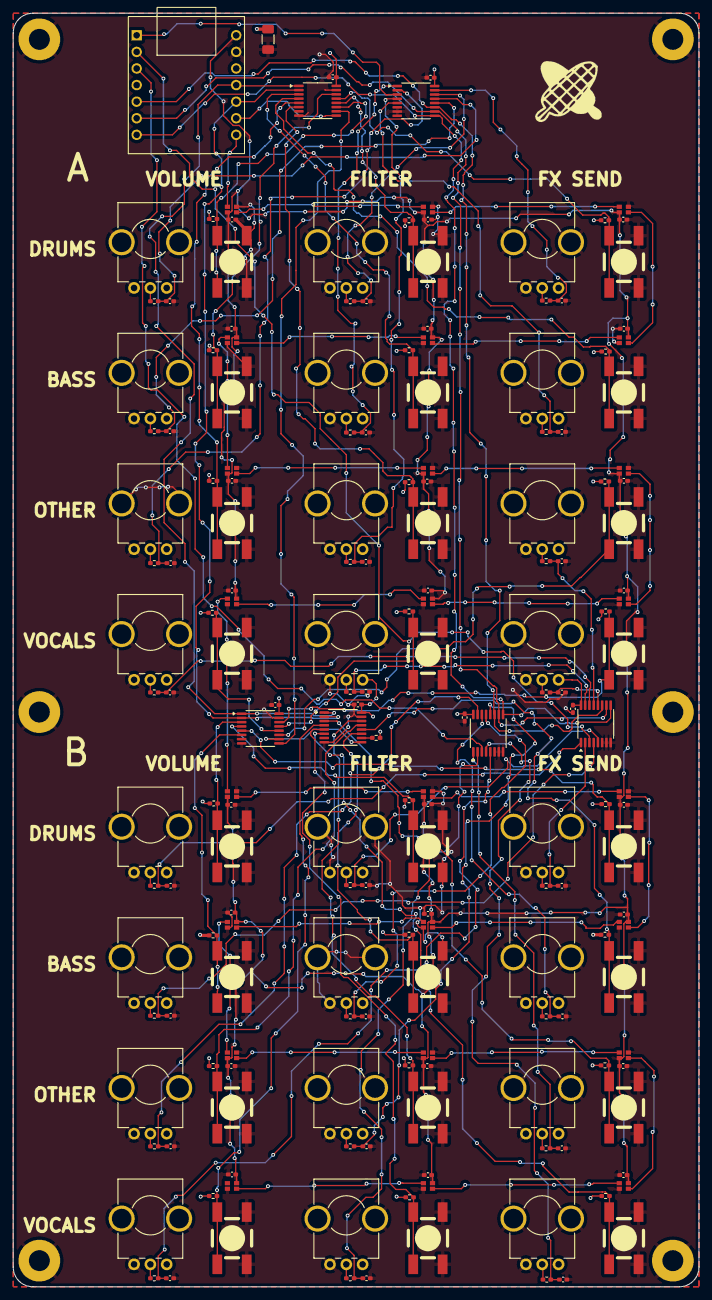
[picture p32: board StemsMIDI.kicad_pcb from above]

Board: 2 copper layers, 105.0 x 195.0 mm, 190 parts (0 on the bottom side), 111 nets.

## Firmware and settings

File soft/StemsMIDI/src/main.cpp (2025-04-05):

#include <Adafruit_TinyUSB.h>
#include <Arduino.h>
#include <MIDI.h>
#include <pico/stdlib.h>
#include <functional>

#include "stemsmidi_pin_config.h"
#include "stemsmidi_led_display.hpp"
#include "stemsmidi_knob.hpp"
#include "stemsmidi_knob_table.h"
#include "stemsmidi_switch_ids.h"
#include "stemsmidi_switch.hpp"
#include "stemsmidi_status.h"
#include "stemsmidi_cc_numbers.h"
#include "stemsmidi_product_test.h"
#include "stemsmidi_device_instances.h"

using namespace kinoshita_lab::stemsmidi;

bool timer_callback(struct repeating_timer* t);
void knob_callback(uint8_t knob_index, uint16_t value);
void switch_callback(uint32_t switch_index, const int off_on);
void main_loop();

Adafruit_USBD_MIDI usb_midi;
MIDI_CREATE_INSTANCE(Adafruit_USBD_MIDI, usb_midi, MIDI_USB);

int8_t knobToCCTable[kNumKnobs] = {
    cc_numbers::kDeckA_Slot1_Volume_Adjust,
    cc_numbers::kDeckA_Slot1_Filter_Adjust,
    cc_numbers::kDeckA_Slot1_FxSend_Adjust,
    cc_numbers::kDeckA_Slot2_Volume_Adjust,
    cc_numbers::kDeckA_Slot2_Filter_Adjust,
    cc_numbers::kDeckA_Slot2_FxSend_Adjust,
    cc_numbers::kDeckA_Slot3_Volume_Adjust,
    cc_numbers::kDeckA_Slot3_Filter_Adjust,
    cc_numbers::kDeckA_Slot3_FxSend_Adjust,
    cc_numbers::kDeckA_Slot4_Volume_Adjust,
    cc_numbers::kDeckA_Slot4_Filter_Adjust,
    cc_numbers::kDeckA_Slot4_FxSend_Adjust,
    cc_numbers::kDeckB_Slot1_Volume_Adjust,
    cc_numbers::kDeckB_Slot1_Filter_Adjust,
    cc_numbers::kDeckB_Slot1_FxSend_Adjust,
    cc_numbers::kDeckB_Slot2_Volume_Adjust,
    cc_numbers::kDeckB_Slot2_Filter_Adjust,
    cc_numbers::kDeckB_Slot2_FxSend_Adjust,
    cc_numbers::kDeckB_Slot3_Volume_Adjust,
    cc_numbers::kDeckB_Slot3_Filter_Adjust,
    cc_numbers::kDeckB_Slot3_FxSend_Adjust,
    cc_numbers::kDeckB_Slot4_Volume_Adjust,
    cc_numbers::kDeckB_Slot4_Filter_Adjust,
    cc_numbers::kDeckB_Slot4_FxSend_Adjust,
};

int8_t switchToCCTable[kNumSwitches] = {
    cc_numbers::kDeckA_Slot1_Mute_OnOff,
    cc_numbers::kDeckA_Slot1_Filter_OnOff,
    cc_numbers::kDeckA_Slot1_FxSend_OnOff,
    cc_numbers::kDeckA_Slot2_Mute_OnOff,
    cc_numbers::kDeckA_Slot2_Filter_OnOff,
    cc_numbers::kDeckA_Slot2_FxSend_OnOff,
    cc_numbers::kDeckA_Slot3_Mute_OnOff,
    cc_numbers::kDeckA_Slot3_Filter_OnOff,
    cc_numbers::kDeckA_Slot3_FxSend_OnOff,
    cc_numbers::kDeckA_Slot4_Mute_OnOff,
    cc_numbers::kDeckA_Slot4_Filter_OnOff,
    cc_numbers::kDeckA_Slot4_FxSend_OnOff,
    cc_numbers::kDeckB_Slot1_Mute_OnOff,
    cc_numbers::kDeckB_Slot1_Filter_OnOff,
    cc_numbers::kDeckB_Slot1_FxSend_OnOff,
    cc_numbers::kDeckB_Slot2_Mute_OnOff,
    cc_numbers::kDeckB_Slot2_Filter_OnOff,
    cc_numbers::kDeckB_Slot2_FxSend_OnOff,
    cc_numbers::kDeckB_Slot3_Mute_OnOff,
    cc_numbers::kDeckB_Slot3_Filter_OnOff,
    cc_numbers::kDeckB_Slot3_FxSend_OnOff,
    cc_numbers::kDeckB_Slot4_Mute_OnOff,
    cc_numbers::kDeckB_Slot4_Filter_OnOff,
    cc_numbers::kDeckB_Slot4_FxSend_OnOff,
};

bool timer_fired = false;
struct repeating_timer timer;

std::function<void()> main_loop_function                             = nullptr;
std::function<bool(struct repeating_timer*)> timer_callback_function = nullptr;

bool timer_callback(struct repeating_timer* t)
{
    timer_fired = true;
    return true;
}

void knob_callback(uint8_t knob_index, uint16_t value)
{
    const auto table_applied_value = knob_table::apply(knob_index, value);
    if (status.knob_scanned_value[knob_index] == table_applied_value) {
        return;
    }

    status.knob_scanned_value[knob_index] = table_applied_value;

    const auto index                        = status.getKnobMidiMessageSlotIndex(knob_index);
    status.midi_messages[index].should_send = true;
    status.midi_messages[index].value       = table_applied_value;
}

void switch_callback(uint32_t switch_index, const int off_on)
{
    const auto index                        = status.getSwitchMidiMessageSlotIndex(switch_index);
    status.midi_messages[index].should_send = true;
    status.midi_messages[index].value       = off_on ? 0 : 127;
}

void handle_control_change(const byte channel, const byte number, const byte value)
{
    if (channel != kMidiChannel) {
        return;
    }

    auto ccToLedId = [](const int cc) -> int {
        using namespace cc_numbers;
        switch (cc) {
        case kDeckA_Slot1_Mute_OnOff:
            return kLed_DeckA_Drums_Volume;
        case kDeckA_Slot1_Filter_OnOff:
            return kLed_DeckA_Drums_Filter;
        case kDeckA_Slot1_FxSend_OnOff:
            return kLed_DeckA_Drums_FxSend;
        case kDeckA_Slot2_Mute_OnOff:
            return kLed_DeckA_Bass_Volume;
        case kDeckA_Slot2_Filter_OnOff:
            return kLed_DeckA_Bass_Filter;
        case kDeckA_Slot2_FxSend_OnOff:
            return kLed_DeckA_Bass_FxSend;
        case kDeckA_Slot3_Mute_OnOff:
            return kLed_DeckA_Other_Volume;
        case kDeckA_Slot3_Filter_OnOff:
            return kLed_DeckA_Other_Filter;
        case kDeckA_Slot3_FxSend_OnOff:
            return kLed_DeckA_Other_FxSend;
        case kDeckA_Slot4_Mute_OnOff:
            return kLed_DeckA_Vocals_Volume;
        case kDeckA_Slot4_Filter_OnOff:
            return kLed_DeckA_Vocals_Filter;
        case kDeckA_Slot4_FxSend_OnOff:
            return kLed_DeckA_Vocals_FxSend;
        case kDeckB_Slot1_Mute_OnOff:
            return kLed_DeckB_Drums_Volume;
        case kDeckB_Slot1_Filter_OnOff:
            return kLed_DeckB_Drums_Filter;
        case kDeckB_Slot1_FxSend_OnOff:
            return kLed_DeckB_Drums_FxSend;
        case kDeckB_Slot2_Mute_OnOff:
            return kLed_DeckB_Bass_Volume;
        case kDeckB_Slot2_Filter_OnOff:
            return kLed_DeckB_Bass_Filter;
        case kDeckB_Slot2_FxSend_OnOff:
            return kLed_DeckB_Bass_FxSend;
        case kDeckB_Slot3_Mute_OnOff:
            return kLed_DeckB_Other_Volume;
        case kDeckB_Slot3_Filter_OnOff:
            return kLed_DeckB_Other_Filter;
        case kDeckB_Slot3_FxSend_OnOff:
            return kLed_DeckB_Other_FxSend;
        case kDeckB_Slot4_Mute_OnOff:
            return kLed_DeckB_Vocals_Volume;
        case kDeckB_Slot4_Filter_OnOff:
            return kLed_DeckB_Vocals_Filter;
        case kDeckB_Slot4_FxSend_OnOff:
            return kLed_DeckB_Vocals_FxSend;
        default:
            return -1;
        }
    };

    const auto led_id = ccToLedId(number);
    if (led_id != -1) {
        const auto off_on = value == 0 ? 0 : 1;
        led_display.setLed(led_id, off_on);
        status.updateLed = true;
    }
}

void set_test_mode()
{
    main_loop_function = product_test::test_loop;
    switches.setHandler(product_test::switch_callback);
    knobs.setHandler(product_test::knob_callback);
    product_test::initialize();
}

void set_normal_mode()
{
    main_loop_function = main_loop;
    switches.setHandler(switch_callback);
    knobs.setHandler(knob_callback);
}

void setup()
{
    Serial.begin(115200);
    // Manual begin() is required on core without built-in support e.g. mbed rp2040
    TinyUSBDevice.setManufacturerDescriptor("Kinoshita Laboratory");
    TinyUSBDevice.setProductDescriptor("Stems MIDI Controller");
    TinyUSBDevice.setSerialDescriptor("0xdeadbeef");
    if (!TinyUSBDevice.isInitialized()) {
        TinyUSBDevice.begin(0);
    }

    usb_midi.setStringDescriptor("Kinoshita Lab. Stems MIDI");

    MIDI_USB.begin();
    MIDI_USB.setThruFilterMode(midi::Thru::Off);
    if (TinyUSBDevice.mounted()) {
        TinyUSBDevice.detach();
        delay(10);
        TinyUSBDevice.attach();
    }

    led_display.init();

    // initialize cc numbers
    for (auto i = 0; i < kNumKnobs; i++) {
        status.midi_messages[Status::getKnobMidiMessageSlotIndex(i)].cc_number = knobToCCTable[i];
    }

    for (auto i = 0; i < kNumSwitches; i++) {
        status.midi_messages[Status::getSwitchMidiMessageSlotIndex(i)].cc_number = switchToCCTable[i];
    }

    // initial switch scan, to determine whether product testing should perform
    switches.forceScan();
    const auto deckADrumsVolSwitchOn    = switches.switchIsOn(kSwitch_DeckA_Drums_Volume);
    const auto deckADrumsFilterSwitchOn = switches.switchIsOn(kSwitch_DeckA_Drums_Filter);
    // enter test mode if both deck A drums volume and filter switches are on.
    if (deckADrumsVolSwitchOn && deckADrumsFilterSwitchOn) {

        set_test_mode();
    } else {
        set_normal_mode();
    }

    product_test::set_test_finish_callback(set_normal_mode);

    // start timer(500us)
    add_repeating_timer_us(500, timer_callback, NULL, &timer);

    MIDI_USB.setHandleControlChange(handle_control_change);

    // failsafe just in case.. do not want to check existence of main_loop_function in loop() every time
    if (!main_loop_function) {
        main_loop_function = main_loop;
    }
}

void loop()
{
    // common implementation
#ifdef TINYUSB_NEED_POLLING_TASK
    // Manual call tud_task since it isn't called by Core's background
    TinyUSBDevice.task();
#endif

    if (timer_fired) {
        timer_fired = false;
        knobs.readKnobs();
        switches.update();
    }

    main_loop_function();

    // update led display
    if (status.updateLed) {
        status.updateLed = false;
        led_display.update();
    }
}

void main_loop()
{
    // send midi messages
    for (auto i = 0; i < kNumTotalTweakableItems; i++) {
        if (status.midi_messages[i].should_send) {
            status.midi_messages[i].should_send = false;

            MIDI_USB.sendControlChange(status.midi_messages[i].cc_number, status.midi_messages[i].value, kMidiChannel);
        }
    }
    // receive midi messages
    MIDI_USB.read();
}

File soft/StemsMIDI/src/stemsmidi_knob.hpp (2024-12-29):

#pragma once
#ifndef STEMSMIDI_KNOBS_HPP
#define STEMSMIDI_KNOBS_HPP

#include <Arduino.h>
#include "stemsmidi_one_pole_filter.hpp"

namespace kinoshita_lab
{
namespace stemsmidi
{

class Knobs
{
    struct Pins
    {
        uint8_t s0;
        uint8_t s1;
        uint8_t s2;

        uint8_t a0;
        uint8_t a1;
        uint8_t a2;

        Pins(const uint8_t s0, const uint8_t s1, const uint8_t s2, const uint8_t a0, const uint8_t a1, const uint8_t a2) : s0{s0}, s1{s1}, s2{s2}, a0{a0}, a1{a1}, a2{a2} {}
    };

    Pins pins_;

    enum
    {
        kNumKnobs          = 24,
        kNumKnobForEachMux = 8,
    };

    uint8_t knob_scan_index_ = 0;
    uint16_t knob_values_[kNumKnobs];
    OnePoleFilter filters_[kNumKnobs];

    void updateKnobIndex()
    {
        knob_scan_index_++;
        if (knob_scan_index_ >= kNumKnobForEachMux) {
            knob_scan_index_ = 0;
        }

        digitalWrite(pins_.s0, knob_scan_index_ & 0x01);
        digitalWrite(pins_.s1, knob_scan_index_ & 0x02);
        digitalWrite(pins_.s2, knob_scan_index_ & 0x04);
    }

public:
    typedef void (*KnobCallback)(uint8_t knob_index, uint16_t value);
    KnobCallback knob_callback_ = nullptr;

    Knobs(
        const uint8_t s0,
        const uint8_t s1,
        const uint8_t s2,
        const uint8_t a0,
        const uint8_t a1,
        const uint8_t a2,
        KnobCallback callback) : pins_{s0, s1, s2, a0, a1, a2}, knob_callback_(callback)
    {
        init();
    }

    ~Knobs() = default;

    void init()
    {
        pinMode(pins_.s0, OUTPUT);
        pinMode(pins_.s1, OUTPUT);
        pinMode(pins_.s2, OUTPUT);

        digitalWrite(pins_.s0, LOW);
        digitalWrite(pins_.s1, LOW);
        digitalWrite(pins_.s2, LOW);
    }

    void readKnobs()
    {
        constexpr int shift = 1;
        const uint16_t a0   = (int)(analogRead(pins_.a0)) >> shift;
        const uint16_t a1   = (int)(analogRead(pins_.a1)) >> shift;
        const uint16_t a2   = (int)(analogRead(pins_.a2)) >> shift;

        auto onChangeEmit = [&](uint8_t knob_index, uint16_t value) {
            filters_[knob_index].update(value);
            const auto output = (uint16_t)(filters_[knob_index].output_);
            const auto delta  = abs(knob_values_[knob_index] - output);

            if (delta > 1 || output == 0 || output == (1023 >> shift)) {
                if (knob_values_[knob_index] != output) {
                    knob_values_[knob_index] = output;
                    if (knob_callback_ != nullptr) {
                        (*knob_callback_)(knob_index, value);
                    }
                }
            }
        };

        onChangeEmit(knob_scan_index_, a0);
        onChangeEmit(knob_scan_index_ + kNumKnobForEachMux, a1);
        onChangeEmit(knob_scan_index_ + kNumKnobForEachMux * 2, a2);

        // prepare for next knob
        updateKnobIndex();
    }

    void setHandler(KnobCallback callback)
    {
        knob_callback_ = callback;
    }
};
} // namespace stemsmidi
} // namespace kinoshita_lab

#endif // STEMSMIDI_KNOBS_HPP

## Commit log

2024-11-02 add hardware files
    [Bottom-Edge_Cuts.dxf, Bottom.kicad_pcb, Case-Edge_Cuts.dxf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]
2024-11-06 implement LED
2024-11-10 README.ja.md の更新
2024-11-15 modify for rev 1.1
    [Bottom-Edge_Cuts.dxf, Bottom.kicad_pcb, Case_acrylic-Edge_Cuts.dxf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]
2024-12-02 [hard] Correct LCSC #
    [StemsMIDI.kicad_sch]
2024-12-02 Add How to assemble in Engligh
2024-12-31 revert Serial disabling, due to the suspect that Serial.end() disables all the USB device features.
    [main.cpp]
2025-04-05 [soft] remove center click plateau for knobs other than filters
2025-04-05 [case] reorganize, rename case and pcb files
    [Bottom-Edge_Cuts.dxf, Bottom.kicad_pcb, Case-Edge_Cuts.dxf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]
